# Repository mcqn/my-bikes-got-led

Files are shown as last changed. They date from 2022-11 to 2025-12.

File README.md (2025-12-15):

# My Bike's Got LED
[My Baby's Got LED](https://github.com/mcqn/my-babys-got-led), bike edition. The same [WLED](https://kno.wled.ge/) fun but without being tied to a wall socket.

ibal234-KensingtonFog

My Bike's got LED is a small, battery powered [ESP32 C3](https://www.espressif.com/en/products/socs/esp32-c3) board designed to drive Neopixel/WS2812 LED strips. The original was created for use on bikes, hence the name, but it works just as well for other wearable/portable light projects. It is intended to be usually powered by lipo batteries via a JST terminal, but an additional power bank source can also be attached via the USB-C socket. 
It is in the process of certification with [OSHWA](https://certification.oshwa.org/) 

Boards are shipped with our [getting started zine](https://github.com/mcqn/my-bikes-got-led/blob/main/mybikesgotzine.svg) below is a more detailed discription of how to set up and use My Bike's got LED

### Setting up your bike

The board kit we [sell on Tindie](https://www.tindie.com/products/mcqn_ltd/my-bikes-got-led/) comes with a strip of LEDs already connected to an Amphenol Anytek plug suitable for the on board [four way pluggable terminal block](https://uk.farnell.com/amphenol-anytek/oq0412510000g/terminal-block-r-a-header-4way/dp/3810182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) My Bike's got LED has two main LED data outputs, Data and Clk. The default channel of Data is used, but the secondary output of Clk can also be used if required. (In fact it is possible to use four level shifted outputs to drive for independent light strips if required, see the additonal notes on the [electronics page](https://github.com/mcqn/my-bikes-got-led/tree/main/electronics) if you want to know more about this.) If you are using your own lights connect the three wires, 5V, GND and Data to the screw terminals on the green plug as indicated on the board silkscreen.

Next you will need to attached the lights to your bike, we use velcro ties but if you don't have any cable ties work just as well. They key thing to be aware of here is that the plug end of the light strip is within reach of where you will attach the board. In our kits we provide a saddle bag to store the board and battery, so the plug end of the strips should be close to the seat post. Check first that the strip and socket reach where you would like them, before then securing the lights in place with the ties. Be careful to avoid any moving parts when you secure your lights in place.

Once the lights are secure you can connect them to the board with the green plug, and connect the main battery to the board via the white JST connector. Then turn on the board with the on/off switch. The first thirty lights on your strip will illumate amber. This is the default WLED configuration, information on how to change this is shown in the next step.

### Setting up the board

When a board running WLED is first turned on it will attempt to connect to a known wifi network. If it doesn't have information about a network, or it is out of range, it will instead set up it's own acess point for configuration. The boards we ship have a fresh install of WLED with no knowledge of your network so they will always start in access point mode.  

#### Connecting to wifi

When the board is in access point mode you will be able to connect another device (Mobile/latop) to that network. 

- Open your wifi settings an look for the networked called WLED-AP
- Connect to it and log on with password wled1234

You will arrive at a page with two options. 

- To the controls
- Wifi settings

Use 'To the controls' if you just want to change the settings, this may be all you need to get your board set up.  See 'effects' below for more information on setting the light patterns.

The Wifi settings takes you through the process of connecting the board to a local network, this is useful if you want to change settings without having to connect to the board AP. Once the device is connected to your network you will be able to access the settings page on any other device connected to that network. You will need to add the SSID and password of the network you want to connect to. It's also a good idea to change the mDNS address to something you can recognise, the default is WLED.

More details on wifi set up can be found on the [WLED documentation](https://kno.wled.ge/basics/getting-started/#wifi-setup)

#### Effects

#### Setting up presets

### Adding usermods
Aside from the LED data outputs there are other GPIO pins available to extend the capability of the board, with WLED user mods. 

If you have a [UK000073](https://certification.oshwa.org/uk000073.html) board pins 0, 1, 3, 4 and 10 are available on header J10.

On version [UK000083](https://certification.oshwa.org/uk000083.html) 0, 1, 4 and 10 are in the circular 'Microphone' header, designed to work with INMP441 microphone breakout boards. Pin 3 is available as 'Button' next to the power header.

Both configurations offer the ability to add an 'effects button' to cycle through preprogrammed lighting effects and to implement sound reative effects with an audio input.

#### Effects button

There are times when you might want to cycle through the effects you have set up. 

......

More information about setting up buttons is available in the [WLED documentation](https://kno.wled.ge/features/macros/#buttons)

#### Sound reactive

There are more instructions in the [WLED documentation](https://mm.kno.wled.ge/WLEDSR/Digital-Microphone-Hookup/)

### Updating the software

WLED is an active project and new version are released often. If you need to update to a more current version of the software there are a few options available.

One route is to use the [unofficial online complier tool](https://wled-compile.github.io/) NB. this requires Chrome/Edge browsers for the Web USB upload to work.

- In step 1 select 'esp32c3dev' as the Microcontroller type and in step 3 tick the 'Audio reactive' box, everything else can be left as default.
- Compile the code, step 5 and then install with the instructions described in step 6.
- Follow the prompts to connect to your wifi
- Once connected click the link to see the controls

You will need to configure the default pin settings and number of leds as well as the pins for the audio input device you are using. See [electronics](https://github.com/mcqn/my-bikes-got-led/tree/main/electronics) for more details about the pinouts.

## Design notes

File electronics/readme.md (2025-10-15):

# My Bikes got LED

The hardware for MBiGL is based around the [ESP32 C3 Mini](https://www.espressif.com/sites/default/files/documentation/esp32-c3-mini-1_datasheet_en.pdf) 

## ESPC3-mini Pins Used

| Pin | Function | Note |
| ---- | ---- | ----|
| IO0 | GPIO | - |
| IO1 | GPIO | - |
| IO3 | GPIO | Also available as a level shifted data output by bridging JP42 |
| IO4 | GPIO | Also available as a level shifted data output by bridging JP43 |
| IO5 | LED_data | |
| IO6 | LED_Clock | |
| IO7 | WiFi LED | |
| IO9 | Boot pin | Access via J11 |
| IO10 | Reset pin | See note below |

## Interfaces

### Coding

Code can be uploaded via USB serial or with an external UART board via J31 (six pin header).
More details on the [Espressif website](https://docs.espressif.com/projects/esp-idf/en/latest/esp32c3/get-started/establish-serial-connection.html)

### RGB data outpus

There are four pins available for RGB data output. LED_data (IO5) and LED_clock (IO6) are the primary outputs. IO3 and IO4 are not connected to the level shifter (U4) by default but can be used as additional channels by bridging JP42 and JP43 with solder if required.

**NB IO3/4 are also available as GPIO pins via J10 but cannot be used for both**

### External Crystal

IO0 and IO1 are used by the C3 mini if an external crystal is required. The first revision had footprints for a crystal but this has now been removed as it isn't needed.
These two pins are available via j10 as GPIO

### Additional pins

IO7 is used to drive the Wifi LED indicator D6

IO9 is used to toggle boot modes and can be accessed via J11 See the [C3 technical manual for more details](https://www.espressif.com/sites/default/files/documentation/esp32-c3_technical_reference_manual_en.pdf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)

~~IO10 is connected to the Enable pin via JP4, a breakable bridge. This pin is used for the reset usermod. In addition to the bridge pad there are two unpopulated 0603 resistors here in case an RC circuit is required for timing. R17 has GND and float pads R18 3V3 and float.~~

These have been removed from production boards.

### Headers

J5 and J6 both provde 5v 3v3 and Gnd outputs via 2.54 header

J40 provides 5V, Data, and GND access as an alternative light connection to the socket J2

## Battery management fine tuning

R23-26 are connected to the battery management chip [IP5310](http://www.injoinic.com/wwwroot/uploads/files/20200221/a7a6128e03ee193cf35e48b28e3df9df.pdf) Only R26 is populated but all are available for fine tuning of the charging circuit functions

| Resistor | Name | Default status |  Function |
| ---- | ---- | ---- | ---- |
| R23 | VSET | DNP | Battery voltage selection | 
| R24 | VTHS | DNP | Battery platform selection |
| R25 | RSET | DNP | Set the battery impendence |
| R26 | NTC | 51K | Detect battery pack temperature |

A test point labeled Key1 is available to break out the Key pin on the IP5310 if push button functionality is required

D1-4 are connected to give a four light 'State of Charge' indication

## Alternate board conifguarations

If a thinner board footprint is required there are alternate pads provided for the USB socket and JST battery connector.
Only one each of the following is required

USBC1 or USBC2

J51 or J52

## Changes to board to accomodate INMP441

Issue 38 suggests adaptions to the board to accomodate a footprint and headers for an INMP441 microphone board.

The reset pin has been removed entirely, reset can be achieved via SW3 making IO10 available. 

L/R selection doubles up on a level shifted output so the microphone is not available if this output is enabled (JP43)

| Pin | INMP441 | Note |
| ---- | ---- | ----|
| IO10 | SD | Previously reset pin |
| IO0 | SCK | - |
| IO01 | WS | - |
| IO04 | L/R | Alt available as level shifted output |

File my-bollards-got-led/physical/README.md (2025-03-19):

# Physical Assembly

## Parts

* 1 x My Bike's Got LED board, with USB connector on the short side and the vertical JST-PH battery connector fitted
* 1 x toggle switch
* 1 x inner end-cap
* 1 x PCB to battery adaptor
* 1 x brace
* 1 x 2x2 18650 battery pack, with JST-PH connector
* 2 x LED strip endcaps
* 3 x 29 LED strips
* 3 x LED backing strips
* Some double-sided tape, unless the LED strips are self-adhesive
* Some electricians tape
* 2 x PVC 50mm plumbing end-caps
* 66cm 50MM frosted polycarbonate tube
* 4 x M3 bolts
* 4 x M3 nuts
* ~20cm of ribbon
* Solvent weld
* An elastic band
* 1 x top cap

## Instructions

### Electronics

1. Solder wires to the toggle switch and then to the two terminals on the PCB, with the wires sitting on the underside of the PCB
1. Solder two sets of LED wiring - power/ground/data - to the underside of the PCB, to 5V/GND and Data and Clk
1. Solder the remaining set of LED wiring to 5V/GND/IO3 on the top side of the PCB, with the solder bridge to enable IO3 on the level-shifter
1. Solder the other ends of the LED wires to the LED strips

### Outer Tube

1. Glue the PVC end-caps onto the polycarb tube with solvent weld

### Inner Assembly

1. Stick the LED strips to the backing strips
1. Fasten the toggle switch into the inner-end-cap
1. Bolt the PCB to the inner-end-cap with two M3 nuts and bolts
1. Feed the two sets of LEDs from the underside of the PCB through the side of the PCB-to-battery adaptor with the notch for the brace
1. Feed the remaining set of LEDs through the other side of the PCB-to-battery adaptor
1. Bolt the PCB to the PCB-to-battery adaptor with two M3 nuts and bolts
1. Attach the brace to the PCB-to-battery adaptor and one of the LED strip endcaps
1. Feed the ribbon through the cut-out in the LED strip endcap and then both ends of it through the PCB-top-side hole in the PCB-to-battery adaptor
1. Insert the battery and feed its wiring through the PCB-top-side hole in the PCB-to-battery adaptor
1. Hook the LED strips onto their relative convenient hooks on the LED endcap, routing the wires around the peg
1. Tape the LED wiring to the side of the battery with some electrician tape, to keep it roughly in place.  Spare wire can be fed through to sit alongside the PCB
1. Hook the other end of the LED strips onto the other LED strip endcap

### Final Assembly

1. Feed some string or wool through the tube, and then through the cut-out in the not-PCB-end LED strip endcap
1. Attach the elastic band through the not-PCB-end LED strip endcap
1. Slowly pull the inner assembly through the tube until the PCB end cap seats onto the PVC endcap
1. Attach the elastic band from the top LED tensioner

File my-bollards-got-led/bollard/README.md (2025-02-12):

| Supported Targets | ESP32 | ESP32-C2 | ESP32-C3 | ESP32-C5 | ESP32-C6 | ESP32-C61 | ESP32-H2 | ESP32-S3 |
| --- | ----- | --- | --- | --- | --- | --- | --- | --- |

ESP-IDF Combined Bluetooth advertising and scanning
===================================================

Copy of this sample as base for Bollard code
todo edit this document to reflect changes to functionality

Have a fixed bollard number 1-4

Separate tasks to manage Bluetooth comms and display

Bluetooth
Maintain list of Parcel devices within given range (RSSI) over the last five seconds and if they are at the correct bollard or not

Listen for Set/Check/Reset broadcasts from controller. Use a hop counter when rebroadcasting this signal to other bollards to extend the range

On Set call display to enter waiting mode
On Check call correct/incorrect display based on state of Parcel devices seen list
On Reset enter waiting mode

Display
Receive calls to set lights based on game state. Ideally animated sequences

This is a Bluetooth advertising and scanning demo with virtual HCI interface. Send Reset, ADV_PARAM, ADV_DATA and HCI_ADV_ENABLE command for BLE advertising. And SET_EVENT_MASK, SCAN_PARAMS and SCAN_START commands for BLE scanning. Scanned advertising reports from other devices are also displayed.

In this example no host is used. But some of the functionalities of a host are implemented.

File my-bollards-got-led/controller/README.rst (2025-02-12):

.. zephyr:code-sample:: ble_peripheral
   :name: Peripheral
   :relevant-api: bt_gatt bluetooth

   Implement basic Bluetooth LE Peripheral role functionality (advertising and exposing GATT services).

Copy of this sample as base for Controller code
todo edit this document to reflect changes to functionality

Manages the game running with button presses

    A Set the game: Broadcast to all bollards to enter waiting mode
    B Check: Broadcast to all the bollards to check status and display correct/incorrect indicator
    A+B Reset Broadcast to all the Parcels to generate a random destination number 1-4 and broadcast to bollards to enter waiting mode

Overview
********

Application demonstrating the Bluetooth LE Peripheral role. It has several well-known and
vendor-specific GATT services that it exposes.

Requirements
************

* BlueZ running on the host, or
* A board with Bluetooth LE support

Building and Running
********************

This sample can be found under :zephyr_file:`samples/bluetooth/peripheral` in the
Zephyr tree.

See :zephyr:code-sample-category:`bluetooth` samples for details.

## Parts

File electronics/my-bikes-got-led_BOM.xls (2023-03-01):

References | Qty | Description | Farnell | Farnell Price/Stock | LCSC | LCSC Price/Stock | Manuf# | description
5V_T1, Clk_T1, Data_T1 | 3 | DNP
BT1 | 1 |  | 9492615 | https://uk.farnell.com/jst-japan-solderless-terminals/s2b-ph-sm4-tb-lf-sn/connector-header-smt-r-a-2mm-2way/dp/9492615
C1, C4 | 2 |  | C342632 | https://www.lcsc.com/product-detail/Multilayer-Ceramic-Capacitors-MLCC-SMD-SMT_TDK-C4532X7R1C226MT000N_C342632.html | C342632 | https://www.lcsc.com/product-detail/Multilayer-Ceramic-Capacitors-MLCC-SMD-SMT_TDK-C4532X7R1C226MT000N_C342632.html
C3 | 1 |  | C28504 | https://www.lcsc.com/product-detail/Multilayer-Ceramic-Capacitors-MLCC-SMD-SMT_FH_1812X226K250NT_22uF-226-10-25V_C28504.html | C28504 | https://www.lcsc.com/product-detail/Multilayer-Ceramic-Capacitors-MLCC-SMD-SMT_FH_1812X226K250NT_22uF-226-10-25V_C28504.html
C5 | 1 |  | C342632 | https://www.lcsc.com/product-detail/Multilayer-Ceramic-Capacitors-MLCC-SMD-SMT_TDK-C4532X7R1C226MT000N_C342632.html | C342632 | https://www.lcsc.com/product-detail/Multilayer-Ceramic-Capacitors-MLCC-SMD-SMT_TDK-C4532X7R1C226MT000N_C342632.html
C6, C8 | 2 |  | C28504 | https://www.lcsc.com/product-detail/Multilayer-Ceramic-Capacitors-MLCC-SMD-SMT_FH_1812X226K250NT_22uF-226-10-25V_C28504.html | C28504 | https://www.lcsc.com/product-detail/Multilayer-Ceramic-Capacitors-MLCC-SMD-SMT_FH_1812X226K250NT_22uF-226-10-25V_C28504.html
C7 | 1 |  | 1759038RL | https://uk.farnell.com/multicomp/mc0603f104z250ct/cap-0-1-f-25v-y5v-0603/dp/1759038RL
C9 | 1 |  | 1759031 | https://uk.farnell.com/multicomp/mc0603b473k250ct/cap-0-047-f-25v-10-x7r-0603/dp/1759031
C10 | 1 |  | 3013512 | https://uk.farnell.com/samsung-electro-mechanics/cl31a106kbhnnne/cap-10uf-50v-mlcc-1206/dp/3013512
C11, C14 | 2 |  | 2211179 | https://uk.farnell.com/tdk/c1608x5r1h105k080ab/cap-1-f-50v-10-x5r-0603/dp/2211179
C12 | 1 |  | 2346906 | https://uk.farnell.com/tdk/c1608x7r1h224k080ab/cap-0-22-f-50v-10-x7r-0603/dp/2346906
C13, C16 | 2 |  | 1759122 | https://uk.farnell.com/multicomp/mc0603b104k500ct/cap-0-1-f-50v-10-x7r-0603/dp/1759122
C15 | 1 |  | 3013512 | https://uk.farnell.com/samsung-electro-mechanics/cl31a106kbhnnne/cap-10uf-50v-mlcc-1206/dp/3013512
D1, D2 | 2 |  | 2322102 | https://uk.farnell.com/wurth-elektronik/155124vs73200/led-1204-b-green-50mcd-573nm/dp/2322102
D3 | 1 |  | 3796308 | https://uk.farnell.com/multicomp-pro/mp008279/led-green-70mcd-576nm-0805/dp/3796308
D4 | 1 |  | 3796325 | https://uk.farnell.com/multicomp-pro/mp008293/led-red-220mcd-626nm-0805/dp/3796325
D5, D6, D7 | 3 |  | 3014176 | https://uk.farnell.com/vishay/v3fl45hm3-h/schottky-rect-single-3a-45v-do/dp/3014176
D8 | 1 |  | 2844819 | https://uk.farnell.com/on-semiconductor/mm3z4v3st1g/zener-diode-4-3v-0-2w-sod-323/dp/2844819
F1, F2 | 2 |  | 1861167RL | https://uk.farnell.com/multicomp/mc36225/fuse-ptc-reset-smd-24v-1-1a/dp/1861167RL
J1 | 1 |  | 3367461 | https://uk.farnell.com/amphenol-fci/12401610e4-2a/usb-conn-3-1-type-c-rcpt-smd/dp/3367461
J2 | 1 |  | 3810182 | https://uk.farnell.com/amphenol-anytek/oq0412510000g/terminal-block-r-a-header-4way/dp/3810182
J3 | 1 |  | 1593412 | https://uk.farnell.com/multicomp/2211s-03g/header-1-row-vert-3way/dp/1593412
J4 | 1 | DNP
J5, J6 | 2 | DNP |  |  |  |  |  | dnp
J7 | 1 | DNP
J8 | 1 | DNP
JP1 | 1 | DNP
JP2 | 1 | DNP
JP3 | 1 | DNP
JP4 | 1 | DNP
JP5 | 1 | DNP
JP6 | 1 | DNP
L1 | 1 |  | C27442 | https://www.lcsc.com/product-detail/Power-Inductors_ReliaPro_SMRH74-220MT_22uH_C27442.html | C27442 | https://www.lcsc.com/product-detail/Power-Inductors_ReliaPro_SMRH74-220MT_22uH_C27442.html
L2 | 1 |  | 2374058 | https://uk.farnell.com/bourns/srf1260a-1r5y/inductor-dual-1-5uh-18-3a-pwr/dp/2374058
L3 | 1 |  | 3380989 | https://uk.farnell.com/wurth-elektronik/7447706101/inductor-aec-q200-100uh-shld-1/dp/3380989
P1, P2 | 2 | DNP
P3, P4 | 2 | DNP
Q1, Q4 | 2 |  | 2769528 | https://uk.farnell.com/rohm/rrr040p03fratl/mosfet-aec-q101-p-ch-30v-tsmt/dp/2769528
Q2 | 1 |  | C32254 | https://www.lcsc.com/product-detail/MOSFET_FORTUNE_FS8205_FS8205_C32254.html | C32254 | https://www.lcsc.com/product-detail/MOSFET_FORTUNE_FS8205_FS8205_C32254.html
Q3 | 1 |  | C916403 | https://www.lcsc.com/product-detail/MOSFETs_JSMSEMI-JSM2302_C916403.html | C916403 | https://www.lcsc.com/product-detail/MOSFETs_JSMSEMI-JSM2302_C916403.html
R1 | 1 |  | 3994449 | https://uk.farnell.com/walsin/mr06x105-jtlv/res-1m-5-0-125w-0603-thick-film/dp/3994449
R2, R3 | 2 |  | 2447404 | https://uk.farnell.com/multicomp/mcwr06x5101ftl/res-5k1-1-0-1w-0603-thick-film/dp/2447404
R4, R26 | 2 |  | 2331740 | https://uk.farnell.com/te-connectivity/crgh0603j10k/res-10k-5-0-2w-0603-thick-film/dp/2331740
R5, R6 | 2 |  | 2502462 | https://uk.farnell.com/walsin/wr06x4700ftl/res-470r-1-75v-0603-thick-film/dp/2502462
R7 | 1 |  | 2073501 | https://uk.farnell.com/multicomp/mcmr06x4302ftl/res-43k-1-0-1w-0603-ceramic/dp/2073501
R8 | 1 |  | 3950855 | https://uk.farnell.com/yageo/rc0603fr-0773k2l/res-73k2-1-0-1w-thick-film-0603/dp/3950855
R9 | 1 |  | 2331740 | https://uk.farnell.com/te-connectivity/crgh0603j10k/res-10k-5-0-2w-0603-thick-film/dp/2331740
R10 | 1 |  | 2447449 | https://uk.farnell.com/multicomp/mcwr06x9102ftl/res-91k-1-0-1w-thick-film/dp/2447449
R11 | 1 |  | 2447293 | https://uk.farnell.com/multicomp/mcwr06x2002ftl/res-20k-1-0-1w-thick-film/dp/2447293
R12, R15, R16 | 3 |  | 2502470 | https://uk.farnell.com/walsin/wr06x5600ftl/res-560r-1-75v-0603-thick-film/dp/2502470
R13, R17 | 2 |  | 2331740 | https://uk.farnell.com/te-connectivity/crgh0603j10k/res-10k-5-0-2w-0603-thick-film/dp/2331740
R14 | 1 |  | 2331740 | https://uk.farnell.com/te-connectivity/crgh0603j10k/res-10k-5-0-2w-0603-thick-film/dp/2331740
R18 | 1 |  | 2502470 | https://uk.farnell.com/walsin/wr06x5600ftl/res-560r-1-75v-0603-thick-film/dp/2502470
R19 | 1 |  | 2447240 | https://uk.farnell.com/multicomp/mcwr06x1200ftl/res-120r-1-0-1w-thick-film/dp/2447240
R20 | 1 |  | 2447338 | https://uk.farnell.com/multicomp/mcwr06x3303ftl/res-330k-1-0-1w-thick-film/dp/2447338
R21 | 1 |  | 2447339 | https://uk.farnell.com/multicomp/mcwr06x3300ftl/res-330r-1-0-1w-0603-thick-film/dp/2447339
R22 | 1 |  | 2447319 | https://uk.farnell.com/multicomp/mcwr06x2001ftl/res-2k-1-0-1w-0603-thick-film/dp/2447319
R23 | 1 |  | 2483502 | https://uk.farnell.com/te-connectivity/tlm2aer068jte/current-sense-res-0r068-5-250/dp/2483502
R24 | 1 |  | 2694684 | https://uk.farnell.com/multicomp/mcwr06x101-jtl/res-100r-5-0-1w-0603-thick-film/dp/2694684
R25, R29 | 2 |  | 2073355 | https://uk.farnell.com/multicomp/mcmr06x1023ftl/res-102k-1-0-1w-0603-ceramic/dp/2073355
R27 | 1 |  | 2331740 | https://uk.farnell.com/te-connectivity/crgh0603j10k/res-10k-5-0-2w-0603-thick-film/dp/2331740
R28 | 1 |  | 2694684 | https://uk.farnell.com/multicomp/mcwr06x101-jtl/res-100r-5-0-1w-0603-thick-film/dp/2694684
SW1 | 1 |  | 2435308 | http://uk.farnell.com/c-k-components/ksek43g-lfs/tactile-switch-spst-0-05a-32vdc/dp/2435308
SW2 | 1 |  | 1201431 | https://uk.farnell.com/c-k-components/os102011ma1qn1/switch-spdt-0-1a-12v-pcb-r-a/dp/1201431
T1, T2 | 2 | DNP
U1 | 1 |  | C82652 | https://www.lcsc.com/product-detail/DC-DC-Converters_Advanced-Analog-Technology-FP6276BXR-G1_C82652.html | C82652 | https://www.lcsc.com/product-detail/DC-DC-Converters_Advanced-Analog-Technology-FP6276BXR-G1_C82652.html
U2 | 1 |  | 3006129 | https://uk.farnell.com/texas-instruments/sn74ahct125d/ic-buffer-gate-quad-3state-smd/dp/3006129
U3 | 1 |  | 2729771 | https://uk.farnell.com/richtek/rt8097bhgb/dc-dc-conv-sync-buck-1mhz-sot/dp/2729771
U4 | 1 | ESP-WROOM-02 free issue |  |  |  |  | ESP-WROOM-02
U5 | 1 |  | C154992 | https://www.lcsc.com/product-detail/Battery-Management-ICs_ShangHai-Consonance-Elec-CN3791_C154992.html | C154992 | https://www.lcsc.com/product-detail/Battery-Management-ICs_ShangHai-Consonance-Elec-CN3791_C154992.html
U6 | 1 |  | C82736 | https://www.lcsc.com/product-detail/Battery-Protection-ICs_FORTUNE_FS312F-G_FS312F-G_C82736.html | C82736 | https://www.lcsc.com/product-detail/Battery-Protection-ICs_FORTUNE_FS312F-G_FS312F-G_C82736.html

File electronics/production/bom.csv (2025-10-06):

Designator | Footprint | Quantity | Value | LCSC Part #
5V_T1, CLK_T1, DATA_T1 | TestPoint_Pad_D2.0mm | 3 | Conn_01x01
C1 | 0603 | 1 | 10uF | C76614
C10, C41 | 0603 | 2 | 0.1uF/50V(10%) | C237171
C11 | 0603 | 1 | 10uF/25V(20%) | C76614
C12 | 0603 | 1 | 1uF/16V(10%) | C85862
C2 | 0603 | 1 | 10uF | C76614
C20, C21 | 0402 | 2 | 22uF | C2179118
C22, C23, C24, C25 | 0402 | 4 | 22uF | C2179118
C31 | 0805 | 1 | 22uF X5R | C128856
C32 | 0805 | 1 | 22uF X5R | C128856
D1, D2, D3, D4 | 0805 | 4 | LED | C965814
D6 | 0805 | 1 | LED | C965815
EN1, EN2 | TestPoint_Pad_D2.5mm | 2 | TestPoint
F1 | 1812 | 1 | Polyfuse | C369172
J12, J13 | PinHeader_1x03_P2.54mm_Vertical | 2 | Conn_01x03
J14 | PinHeader_1x01_P2.54mm_Vertical | 1 | Conn_01x01_Pin
J51 | JST_PH_S2B-PH-SM4-TB_1x02-1MP_P2.00mm_Horizontal | 1 | Battery | C295747
JP42 | SolderJumper-2_P1.3mm_Open_RoundedPad1.0x1.5mm | 1 | P3 EN
JP43 | SolderJumper-2_P1.3mm_Open_RoundedPad1.0x1.5mm | 1 | p16 EN
JP5 | SolderJumper-2_P1.3mm_Open_RoundedPad1.0x1.5mm | 1 | Jumper_on
KEY1 | TestPoint_Pad_D2.0mm | 1 | TestPoint
L2 | IND-SMD_L11.6-W10.1 | 1 | MHCC10040-1R0M-R7 | C280565
L3 | L_Vishay_IHLP-2525 | 1 | 1.5uH | C845020
Q1 | SOT-23 | 1 | JSM2302 | C916403
R1 | 0402 | 1 | 1M | C26083
R11, R22 | 0603 | 2 | 10k | C95204
R12 | 0402 | 1 | R560 | C163460
R13, R14 | 0402 | 2 | 10k | C2073569
R15, R16 | 0402 | 2 | 22 | C25092
R2, R3 | 0402 | 2 | 5.1K | C103079
R20 | 0402 | 1 | 0 | C17168
R21 | 0603 | 1 | 100K | C667752
R26 | 0603 | 1 | 51K | C269448
R27 | 0603 | 1 | R120 | C22787
R31 | 0603 | 1 | 91K | C23265
R32 | 0603 | 1 | 20K | C136589
R4 | 0603 | 1 | 2R | C445777
R41, R42, R5, R6 | 0603 | 4 | 470R | C144600
U1 | WIFIM-SMD_ESP32-C3-MINI-1 | 1 | ESP32-C3-MINI-1-N4 | C2838502
U2 | QFN-32_L5.0-W5.0-P0.50-BL-EP3.4 | 1 | IP5310 | C191176
U3 | SOT-23-5 | 1 | RT8097B | C3031686
U4 | HTSSOP-14-1EP_4.4x5mm_P0.65mm_EP3.4x5mm_Mask3x3.1mm | 1 | SN74AHCT125 | C36365
USBC1 | USB-C-SMD_TYPE-C-USB-18 | 1 | 105450-0101 | C134092

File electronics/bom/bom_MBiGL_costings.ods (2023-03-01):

EUROPEAN CIRCUITS LIMITED - EXAMPLE BILL OF MATERIALS (BOM)
SALES@EUROPEAN-CIRCUITS.CO.UK
Place your mouse over the red comment markers in the top right corner of the cells in the row below to see more info on the data in that column
Company Name: |  |  | MCQN
Board Reference: |  |  | My Bike’s got LED
Revision Number: |  |  | r20221221
1 | 2 | 3 | 4 | 5 | 6 | 7 | 8 | 9 | 10 | 11 | Component costs
Sequential Item Nos | Consolidated quantity of each Part No | Component ID's separated by Commas | Confirmation Yes or No Parts are fitted this Build (Note 1) | Full Description of Part e.g. for capacitor include value, tolerance and type or Dielectric | Value or Type No | Case Style | Supplier or Manufacturer (Note 2) | Supplier Stock No or Manufacturer's Part No (Note 2) | Side of Board Mounted | PTH or SMT | For 6 |  | For 100
Item | Qty | Reference | Fit | Part Description | Value | Package | Supplier | Supplier Ref | Side | Mount Type | ea |  | ea
1 | 3 | 5V_T1, Clk_T1, Data_T1 | DNP |  |  |  |  |  | F |  | 0 |  | 0
2 | 1 | BT1 | Y |  |  |  | https://uk.farnell.com/jst-japan-solderless-terminals/s2b-ph-sm4-tb-lf-sn/connector-header-smt-r-a-2mm-2way/dp/9492615 | 9492615 | F |  | 0.4752 | 2.8512 | 0.3924 | 39.24
3 | 2 | C1, C4 | Y |  |  |  | https://www.lcsc.com/product-detail/Multilayer-Ceramic-Capacitors-MLCC-SMD-SMT_TDK-C4532X7R1C226MT000N_C342632.html | C342632 | F |  | 0.51 | 6.12 | 0.5048 | 100.96
4 | 1 | C3 | Y |  |  |  | https://www.lcsc.com/product-detail/Multilayer-Ceramic-Capacitors-MLCC-SMD-SMT_FH_1812X226K250NT_22uF-226-10-25V_C28504.html | C28504 | F |  | 0.6486 | 3.8916 | 0.4354 | 43.54
5 | 1 | C5 | Y |  |  |  | https://www.lcsc.com/product-detail/Multilayer-Ceramic-Capacitors-MLCC-SMD-SMT_TDK-C4532X7R1C226MT000N_C342632.html | C342632 | F |  | 0.5137 | 3.0822 | 0.5048 | 50.48
6 | 2 | C6, C8 | Y |  |  |  | https://www.lcsc.com/product-detail/Multilayer-Ceramic-Capacitors-MLCC-SMD-SMT_FH_1812X226K250NT_22uF-226-10-25V_C28504.html | C28504 | F |  | 0.6486 | 7.7832 | 0.4354 | 87.08
7 | 1 | C7 | Y |  |  |  | https://uk.farnell.com/multicomp/mc0603f104z250ct/cap-0-1-f-25v-y5v-0603/dp/1759038RL | 1759038RL | F |  | 0.0256 | 0.1536 | 0.0256 | 2.56
8 | 1 | C9 | Y |  |  |  | https://uk.farnell.com/multicomp/mc0603b473k250ct/cap-0-047-f-25v-10-x7r-0603/dp/1759031 | 1759031 | F |  | 0.0443 | 0.2658 | 0.0332 | 3.32
9 | 1 | C10 | Y |  |  |  | https://uk.farnell.com/samsung-electro-mechanics/cl31a106kbhnnne/cap-10uf-50v-mlcc-1206/dp/3013512 | 3013512 | F |  | 0.3072 | 1.8432 | 0.186 | 18.6
10 | 2 | C11, C14 | Y |  |  |  | https://uk.farnell.com/tdk/c1608x5r1h105k080ab/cap-1-f-50v-10-x5r-0603/dp/2211179 | 2211179 | F |  | 0.0865 | 1.038 | 0.0727 | 14.54
11 | 1 | C12 | Y |  |  |  | https://uk.farnell.com/tdk/c1608x7r1h224k080ab/cap-0-22-f-50v-10-x7r-0603/dp/2346906 | 2346906 | F |  | 0.0826 | 0.4956 | 0.0688 | 6.88
12 | 2 | C13, C16 | Y |  |  |  | https://uk.farnell.com/multicomp/mc0603b104k500ct/cap-0-1-f-50v-10-x7r-0603/dp/1759122 | 1759122 | F |  | 0.0306 | 0.3672 | 0.023 | 4.6
13 | 1 | C15 | Y |  |  |  | https://uk.farnell.com/samsung-electro-mechanics/cl31a106kbhnnne/cap-10uf-50v-mlcc-1206/dp/3013512 | 3013512 | F |  | 0.3072 | 1.8432 | 0.186 | 18.6
14 | 2 | D1, D2 | Y |  |  |  | https://uk.farnell.com/wurth-elektronik/155124vs73200/led-1204-b-green-50mcd-573nm/dp/2322102 | 2322102 | F |  | 0.2232 | 2.6784 | 0.1728 | 34.56
15 | 1 | D3 | Y |  |  |  | https://uk.farnell.com/multicomp-pro/mp008279/led-green-70mcd-576nm-0805/dp/3796308 | 3796308 | F |  | 0.1284 | 0.7704 | 0.0853 | 8.53
16 | 1 | D4 | Y |  |  |  | https://uk.farnell.com/multicomp-pro/mp008293/led-red-220mcd-626nm-0805/dp/3796325 | 3796325 | F |  | 0.1184 | 0.7104 | 0.079 | 7.9
17 | 3 | D5, D6, D7 | Y |  |  |  | https://uk.farnell.com/vishay/v3fl45hm3-h/schottky-rect-single-3a-45v-do/dp/3014176 | 3014176 | F |  | 0.4224 | 7.6032 | 0.2004 | 60.12
18 | 1 | D8 | Y |  |  |  | https://uk.farnell.com/on-semiconductor/mm3z4v3st1g/zener-diode-4-3v-0-2w-sod-323/dp/2844819 | 2844819 | F |  | 0.1692 | 1.0152 | 0.084 | 8.4
19 | 2 | F1, F2 | Y |  |  |  | https://uk.farnell.com/multicomp/mc36225/fuse-ptc-reset-smd-24v-1-1a/dp/1861167RL | 1861167RL | F |  | 0.1572 | 1.8864 | 0.1572 | 31.44 | Min order 100
20 | 1 | J1 | Y |  |  |  | https://uk.farnell.com/amphenol-fci/12401610e4-2a/usb-conn-3-1-type-c-rcpt-smd/dp/3367461 | 3367461 | F |  | 1.896 | 11.376 | 1.896 | 189.6
21 | 1 | J2 | Y |  |  |  | https://uk.farnell.com/amphenol-anytek/oq0412510000g/terminal-block-r-a-header-4way/dp/3810182 | 3810182 | F |  | 0.414 | 2.484 | 0.3072 | 30.72 | Min order 10
22 | 1 | J3 | Y |  |  |  | https://uk.farnell.com/multicomp/2211s-03g/header-1-row-vert-3way/dp/1593412 | 1593412 | F |  | 0.0205 | 0.123 | 0.0205 | 2.05 | Min order 50 | Not needed?
23 | 1 | J4 | DNP |  |  |  |  |  | F |  | 0 |  | 0
24 | 2 | J5, J6 | DNP |  |  |  |  |  | F |  | 0 |  | 0
25 | 1 | J7 | DNP |  |  |  |  |  | F |  | 0 |  | 0
26 | 1 | J8 | DNP |  |  |  |  |  | F |  | 0 |  | 0
27 | 1 | JP1 | DNP |  |  |  |  |  | F |  | 0 |  | 0
28 | 1 | JP2 | DNP |  |  |  |  |  | F |  | 0 |  | 0
29 | 1 | JP3 | DNP |  |  |  |  |  | F |  | 0 |  | 0
30 | 1 | JP4 | DNP |  |  |  |  |  | F |  | 0 |  | 0
31 | 1 | JP5 | DNP |  |  |  |  |  | F |  | 0 |  | 0
32 | 1 | JP6 | DNP |  |  |  |  |  | F |  | 0 |  | 0
33 | 1 | L1 | Y |  |  |  | https://www.lcsc.com/product-detail/Power-Inductors_ReliaPro_SMRH74-220MT_22uH_C27442.html | C27442 | F |  | 0.1574 | 0.9444 | 0.1277 | 12.77
34 | 1 | L2 | Y |  |  |  | https://uk.farnell.com/bourns/srf1260a-1r5y/inductor-dual-1-5uh-18-3a-pwr/dp/2374058 | 2374058 | F |  | 1.536 | 9.216 | 1.0368 | 103.68
35 | 1 | L3 | Y |  |  |  | https://uk.farnell.com/wurth-elektronik/7447706101/inductor-aec-q200-100uh-shld-1/dp/3380989 | 3380989 | F |  | 1.308 | 7.848 | 1.0308 | 103.08
36 | 2 | P1, P2 | DNP |  |  |  |  |  | F |  | 0 |  | 0
37 | 2 | P3, P4 | DNP |  |  |  |  |  | F |  | 0 |  | 0
38 | 2 | Q1, Q4 | Y |  |  |  | https://uk.farnell.com/rohm/rrr040p03fratl/mosfet-aec-q101-p-ch-30v-tsmt/dp/2769528 | 2769528 | F |  | 0.8448 | 10.1376 | 0.5904 | 118.08
39 | 1 | Q2 | Y |  |  |  | https://www.lcsc.com/product-detail/MOSFET_FORTUNE_FS8205_FS8205_C32254.html | C32254 | F |  | 0.1489 | 0.8934 | 0.1208 | 12.08
40 | 1 | Q3 | Y |  |  |  | https://www.lcsc.com/product-detail/MOSFETs_JSMSEMI-JSM2302_C916403.html | C916403 | F |  | 0.0226 | 0.1356 | 0.0226 | 2.26 | Min order 20
41 | 1 | R1 | Y |  |  |  | https://uk.farnell.com/walsin/mr06x105-jtlv/res-1m-5-0-125w-0603-thick-film/dp/3994449 | 3994449 | F |  | 0.0028 | 0.0168 | 0.0026 | 0.26 | Min order 10
42 | 2 | R2, R3 | Y |  |  |  | https://uk.farnell.com/multicomp/mcwr06x5101ftl/res-5k1-1-0-1w-0603-thick-film/dp/2447404 | 2447404 | F |  | 0.0049 | 0.0588 | 0.0046 | 0.92 | Min order 10
43 | 2 | R4, R26 | Y |  |  |  | https://uk.farnell.com/te-connectivity/crgh0603j10k/res-10k-5-0-2w-0603-thick-film/dp/2331740 | 2331740 | F |  | 0.0269 | 0.3228 | 0.0269 | 5.38 | Min order 10
44 | 2 | R5, R6 | Y |  |  |  | https://uk.farnell.com/walsin/wr06x4700ftl/res-470r-1-75v-0603-thick-film/dp/2502462 | 2502462 | F |  | 0.0146 | 0.1752 | 0.0053 | 1.06 | Min order 10
45 | 1 | R7 | Y |  |  |  | https://uk.farnell.com/multicomp/mcmr06x4302ftl/res-43k-1-0-1w-0603-ceramic/dp/2073501 | 2073501 | F |  | 0.0092 | 0.0552 | 0.008 | 0.8 | Min order 10
46 | 1 | R8 | Y |  |  |  | https://uk.farnell.com/yageo/rc0603fr-0773k2l/res-73k2-1-0-1w-thick-film-0603/dp/3950855 | 3950855 | F |  | 0.0144 | 0.0864 | 0.0048 | 0.48 | Min order 10
47 | 1 | R9 | Y |  |  |  | https://uk.farnell.com/te-connectivity/crgh0603j10k/res-10k-5-0-2w-0603-thick-film/dp/2331740 | 2331740 | F |  | 0.0226 | 0.1356 | 0.0226 | 2.26
48 | 1 | R10 | Y |  |  |  | https://uk.farnell.com/multicomp/mcwr06x9102ftl/res-91k-1-0-1w-thick-film/dp/2447449 | 2447449 | F |  | 0.0226 | 0.1356 | 0.0226 | 2.26
49 | 1 | R11 | Y |  |  |  | https://uk.farnell.com/multicomp/mcwr06x2002ftl/res-20k-1-0-1w-thick-film/dp/2447293 | 2447293 | F |  | 0.0226 | 0.1356 | 0.0226 | 2.26
50 | 3 | R12, R15, R16 | Y |  |  |  | https://uk.farnell.com/walsin/wr06x5600ftl/res-560r-1-75v-0603-thick-film/dp/2502470 | 2502470 | F |  | 0.0226 | 0.4068 | 0.0226 | 6.78
51 | 2 | R13, R17 | Y |  |  |  | https://uk.farnell.com/te-connectivity/crgh0603j10k/res-10k-5-0-2w-0603-thick-film/dp/2331740 | 2331740 | F |  | 0.0226 | 0.2712 | 0.0226 | 4.52
52 | 1 | R14 | Y |  |  |  | https://uk.farnell.com/te-connectivity/crgh0603j10k/res-10k-5-0-2w-0603-thick-film/dp/2331740 | 2331740 | F |  | 0.0226 | 0.1356 | 0.0226 | 2.26
53 | 1 | R18 | Y |  |  |  | https://uk.farnell.com/walsin/wr06x5600ftl/res-560r-1-75v-0603-thick-film/dp/2502470 | 2502470 | F |  | 0.0226 | 0.1356 | 0.0226 | 2.26
54 | 1 | R19 | Y |  |  |  | https://uk.farnell.com/multicomp/mcwr06x1200ftl/res-120r-1-0-1w-thick-film/dp/2447240 | 2447240 | F |  | 0.0226 | 0.1356 | 0.0226 | 2.26
55 | 1 | R20 | Y |  |  |  | https://uk.farnell.com/multicomp/mcwr06x3303ftl/res-330k-1-0-1w-thick-film/dp/2447338 | 2447338 | F |  | 0.0226 | 0.1356 | 0.0226 | 2.26
56 | 1 | R21 | Y |  |  |  | https://uk.farnell.com/multicomp/mcwr06x3300ftl/res-330r-1-0-1w-0603-thick-film/dp/2447339 | 2447339 | F |  | 0.0226 | 0.1356 | 0.0226 | 2.26
57 | 1 | R22 | Y |  |  |  | https://uk.farnell.com/multicomp/mcwr06x2001ftl/res-2k-1-0-1w-0603-thick-film/dp/2447319 | 2447319 | F |  | 0.0226 | 0.1356 | 0.0226 | 2.26
58 | 1 | R23 | Y |  |  |  | https://uk.farnell.com/te-connectivity/tlm2aer068jte/current-sense-res-0r068-5-250/dp/2483502 | 2483502 | F |  | 0.0226 | 0.1356 | 0.0226 | 2.26
59 | 1 | R24 | Y |  |  |  | https://uk.farnell.com/multicomp/mcwr06x101-jtl/res-100r-5-0-1w-0603-thick-film/dp/2694684 | 2694684 | F |  | 0.0226 | 0.1356 | 0.0226 | 2.26
60 | 2 | R25, R29 | Y |  |  |  | https://uk.farnell.com/multicomp/mcmr06x1023ftl/res-102k-1-0-1w-0603-ceramic/dp/2073355 | 2073355 | F |  | 0.0226 | 0.2712 | 0.0226 | 4.52
61 | 1 | R27 | Y |  |  |  | https://uk.farnell.com/te-connectivity/crgh0603j10k/res-10k-5-0-2w-0603-thick-film/dp/2331740 | 2331740 | F |  | 0.0269 | 0.1614 | 0.0269 | 2.69 | Min order 10
62 | 1 | R28 | Y |  |  |  | https://uk.farnell.com/multicomp/mcwr06x101-jtl/res-100r-5-0-1w-0603-thick-film/dp/2694684 | 2694684 | F |  | 0.0048 | 0.0288 | 0.0044 | 0.44 | Min order 10
63 | 1 | SW1 | Y |  |  |  | http://uk.farnell.com/c-k-components/ksek43g-lfs/tactile-switch-spst-0-05a-32vdc/dp/2435308 | 2435308 | F |  | 0.4296 | 2.5776 | 0.3516 | 35.16 | Min order 10
64 | 1 | SW2 | Y |  |  |  | https://uk.farnell.com/c-k-components/os102011ma1qn1/switch-spdt-0-1a-12v-pcb-r-a/dp/1201431 | 1201431 | F |  | 0.5256 | 3.1536 | 0.438 | 43.8 | Min order 10
65 | 2 | T1, T2 | DNP |  |  |  |  |  | F |  | 0 |  | 0
66 | 1 | U1 | Y |  |  |  | https://www.lcsc.com/product-detail/DC-DC-Converters_Advanced-Analog-Technology-FP6276BXR-G1_C82652.html | C82652 | F
67 | 1 | U2 | Y |  |  |  | https://uk.farnell.com/texas-instruments/sn74ahct125d/ic-buffer-gate-quad-3state-smd/dp/3006129 | 3006129 | F |  | 2.196 | 13.176 | 1.32 | 132
68 | 1 | U3 | Y |  |  |  | https://uk.farnell.com/richtek/rt8097bhgb/dc-dc-conv-sync-buck-1mhz-sot/dp/2729771 | 2729771 | F |  | 0.289 | 1.734 | 0.289 | 28.9 | https://www.lcsc.com/product-detail/DC-DC-Converters_Richtek-Tech-RT8097BHGE_C3200266.html
69 | 1 | U4 | ESP-WROOM-02 free issue |  |  |  |  |  | F |  | 0 |  | 0
70 | 1 | U5 | Y |  |  |  | https://www.lcsc.com/product-detail/Battery-Management-ICs_ShangHai-Consonance-Elec-CN3791_C154992.html | C154992 | F |  | 0.497 | 2.982 | 0.3494 | 34.94
71 | 1 | U6 | Y |  |  |  | https://www.lcsc.com/product-detail/Battery-Protection-ICs_FORTUNE_FS312F-G_FS312F-G_C82736.html | C82736 | F |  | 0.119 | 0.714 | 0.099 | 9.9
 |  |  |  |  |  |  |  |  |  |  | For all | 115.2402 |  | 1453.08
 |  |  |  |  |  |  |  |  |  |  | Each | 19.2067 |  | 14.5308

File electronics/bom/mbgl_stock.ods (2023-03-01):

null | Sourced | Placed | References | Value | Footprint | Quantity | Stock
1 |  |  | C1, C6, C7 | 470uF | C_Elec_10x10.2 | 3 | 11
2 |  |  | C3, C5 | 0.1uF | C_0603_1608Metric_Pad1.05x0.95mm_HandSolder | 2
3 |  |  | C2 | C47nF | C_0603_1608Metric_Pad1.05x0.95mm_HandSolder | 1
4 | ✓ |  | C4 | 10uF | C_1206_3216Metric_Pad1.42x1.75mm_HandSolder | 1
5 |  |  | R6, R7, R8, R9 | R560 | R_0603_1608Metric_Pad1.05x0.95mm_HandSolder | 4
6 | ✓ |  | R1, R2, R10 | R10k | R_0603_1608Metric_Pad1.05x0.95mm_HandSolder | 3
7 |  |  | R3, R4, R5 | 470R | R_0603_1608Metric_Pad1.05x0.95mm_HandSolder | 3
8 |  |  | D4, D5, D6 | LED | LED_0805_2012Metric_Pad1.15x1.40mm_HandSolder | 3 | ~70
9 |  |  | U1 | ESP-13-WROOM-02 | ESP-WROOM-02 | 1 | >100
10 | ✓ |  | U2 | SN74AHCT125 | SOIC-14_3.9x8.7mm_P1.27mm | 1 | ~60
11 |  |  | U3 | LM1117-3.3 | SOT-223-3_TabPin2 | 1 | ~30
12 |  |  | F2, F3, F4 | Fuse | Fuseholder_Cylinder-5x20mm_Wurth_WR-FSH_Horizontal | 3 | ~20
13 |  |  | F1 | Polyfuse | Fuse_1812_4532Metric_Pad1.30x3.40mm_HandSolder | 1 | ~15
14 |  |  | SW1 | Reset | SW_SPST_GULLWING | 1
15 |  |  | G***, G*** | LOGO | mcqn-logo-30mm | 2
16 |  |  | Q1 | NJT4031NT1G | SOT-223-3_TabPin2 | 1 | >50
17 |  |  | J1 | APA102 | PhoenixContact_MSTBVA_2,5_8-G-5,08_1x08_P5.08mm_Vertical | 1 | ~16
18 |  |  | J2 | WS2812 | PinHeader_1x03_P2.54mm_Vertical | 1
19 |  |  | J3 | Serial | PinHeader_1x06_P2.54mm_Vertical | 1
20 |  |  | P1, P2 | CONN_01X09 | PinSocket_1x09_P2.54mm_Vertical | 2
21 |  |  | P3 | ATX_Power_2x12_Connector | Molex_44206-0007_socket_(ATX_power) | 1

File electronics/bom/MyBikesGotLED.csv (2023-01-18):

Id | Designator | Footprint | Quantity | Designation | Supplier and ref
1 | J3 | PinHeader_1x03_P2.54mm_Horizontal | 1 | WS2812
2 | R4,R26 | R_0603_1608Metric_Pad0.98x0.95mm_HandSolder | 2 | R10K
3 | C6,C8 | C_1812_4532Metric_Pad1.57x3.40mm_HandSolder | 2 | 22uF X5R
4 | C5 | C_0603_1608Metric_Pad1.08x0.95mm_HandSolder | 1 | 100uF
5 | R9 | R_0603_1608Metric_Pad0.98x0.95mm_HandSolder | 1 | 10K
6 | R2,R3 | R_0603_1608Metric_Pad0.98x0.95mm_HandSolder | 2 | 5.1K
7 | U2 | SOIC-14_3.9x8.7mm_P1.27mm | 1 | SN74AHCT125
8 | R10 | R_0603_1608Metric_Pad0.98x0.95mm_HandSolder | 1 | 90K
9 | P1,P2 | PinHeader_1x01_P2.54mm_Vertical | 2 | Conn_01x01
10 | U1 | Diodes_SO-8EP | 1 | FP6276B Boost_Convertor
11 | F1,F2 | Fuse_1812_4532Metric_Pad1.30x3.40mm_HandSolder | 2 | Polyfuse
12 | T1,T2 | TestPoint_Pad_D2.0mm | 2 | CONN_01X01
13 | SW1 | SW_SPST_GULLWING | 1 | Reset
14 | R1 | R_0603_1608Metric_Pad0.98x0.95mm_HandSolder | 1 | 1M
15 | 5V_T1,Clk_T1,Data_T1 | TestPoint_Pad_D2.0mm | 3 | Conn_01x01
16 | C3 | C_0603_1608Metric_Pad1.08x0.95mm_HandSolder | 1 | 1nF
17 | C4,C1 | C_1812_4532Metric_Pad1.57x3.40mm_HandSolder | 2 | 22uF
18 | J1 | USB_C_Receptacle_Amphenol_12401610E4-2A | 1 | USB_C_Receptacle
19 | L1 | L_7.3x7.3_H3.5 | 1 | 3.3uH
20 | L2 | L_12x12mm_H6mm | 1 | 1.5uH
21 | R12,R15,R16 | R_0603_1608Metric_Pad0.98x0.95mm_HandSolder | 3 | R560
22 | R13,R14,R17 | R_0603_1608Metric_Pad0.98x0.95mm_HandSolder | 3 | R10k
23 | U4 | ESP-WROOM-02 | 1 | ESP-13-WROOM-02
24 | U5 | SSOP-10_3.9x4.9mm_P1.00mm | 1 | CN3791
25 | Q2 | SOT-23-6 | 1 | FS8205
26 | R6,R5 | R_0603_1608Metric_Pad0.98x0.95mm_HandSolder | 2 | 470R
27 | R18,R27 | R_0603_1608Metric_Pad0.98x0.95mm_HandSolder | 2 | R_Small
28 | SW2 | SW_CuK_OS102011MA1QN1_SPDT_Angled | 1 | ON/OFF
29 | C7,C16,C13 | C_0603_1608Metric_Pad1.08x0.95mm_HandSolder | 3 | 0.1uF
30 | J5,J6 | PinHeader_1x03_P2.54mm_Vertical | 2 | Conn_01x03
31 | D5,D6,D7 | D_SMF | 3 | D_Schottky
32 | J2 | OQ0412510000G | 1 | Conn_01x04
33 | R7 | R_0603_1608Metric_Pad0.98x0.95mm_HandSolder | 1 | 43K
34 | R8 | R_0603_1608Metric_Pad0.98x0.95mm_HandSolder | 1 | 73K
35 | J7 | OQ0212510000G | 1 | Solar Input
36 | JP4 | SolderJumper-2_P1.3mm_Bridged_RoundedPad1.0x1.5mm | 1 | Jumper_2_Bridged
37 | R28,R23 | R_0805_2012Metric_Pad1.20x1.40mm_HandSolder | 2 | Rcs
38 | C12 | C_0603_1608Metric_Pad1.08x0.95mm_HandSolder | 1 | 220nF
39 | J8 | PinHeader_1x02_P2.54mm_Vertical | 1 | Battery
40 | C14,C11 | C_0603_1608Metric_Pad1.08x0.95mm_HandSolder | 2 | 1uF
41 | D2,D1 | LED_0805_2012Metric_Pad1.15x1.40mm_HandSolder | 2 | LED
42 | R29,R25 | R_0603_1608Metric_Pad0.98x0.95mm_HandSolder | 2 | 100K
43 | R24 | R_0603_1608Metric_Pad0.98x0.95mm_HandSolder | 1 | 100R
44 | D8 | D_SOD-323 | 1 | MM3Z4V3ST1G
45 | J4 | PinHeader_1x06_P2.54mm_Vertical | 1 | Serial
46 | R22,R21 | R_0805_2012Metric_Pad1.20x1.40mm_HandSolder | 2 | R_Small
47 | D4 | LED_0805_2012Metric_Pad1.15x1.40mm_HandSolder | 1 | LED Red
48 | R20 | R_0603_1608Metric_Pad0.98x0.95mm_HandSolder | 1 | 320K
49 | Q3 | SOT-23 | 1 | JSM2302
50 | C10,C15 | C_1206_3216Metric_Pad1.33x1.80mm_HandSolder | 2 | 10uF 50V
51 | D3 | LED_0805_2012Metric_Pad1.15x1.40mm_HandSolder | 1 | LED Green
52 | L3 | L_12x12mm_H6mm | 1 | 100uH 2.5A
53 | R19 | R_0603_1608Metric_Pad0.98x0.95mm_HandSolder | 1 | 120R
54 | Q4,Q1 | SOT-23 | 2 | P-channel 30V 4A MOSfet
55 | BT1 | JST_PH_S2B-PH-SM4-TB_1x02-1MP_P2.00mm_Horizontal | 1 | Battery_Cell
56 | JP5 | SolderJumper-2_P1.3mm_Bridged2Bar_RoundedPad1.0x1.5mm | 1 | Test Point
57 | JP1 | SolderJumper-2_P1.3mm_Open_RoundedPad1.0x1.5mm | 1 | FTDI_PWR
58 | P3,P4 | PinSocket_1x09_P2.54mm_Vertical | 2 | CONN_01X09
59 | R11 | R_0603_1608Metric_Pad0.98x0.95mm_HandSolder | 1 | 20K
60 | JP2 | SolderJumper-2_P1.3mm_Open_RoundedPad1.0x1.5mm | 1 | p16 EN
61 | JP6 | SolderJumper-2_P1.3mm_Open_RoundedPad1.0x1.5mm | 1 | Jumper_on
62 | JP3 | SolderJumper-2_P1.3mm_Open_RoundedPad1.0x1.5mm | 1 | P5 EN
63 | U3 | SOT-23-5 | 1 | RT8097B
64 | U6 | SOT-23-6_Handsoldering | 1 | FS312F-G
65 | C9 | C_0603_1608Metric_Pad1.08x0.95mm_HandSolder | 1 | C47nF
66 | G*** | mcqn-logo-20mm | 1 | LOGO

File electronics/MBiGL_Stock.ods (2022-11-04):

null | Sourced | Placed | References | Value | Footprint | Quantity |  | Stock
1 |  |  | C3, C4, C6, C8 | 22uF X5R | C_1812_4532Metric_Pad1.57x3.40mm_HandSolder | 4 |  | 48
2 |  |  | C1 | 0.1uF | C_0603_1608Metric_Pad1.08x0.95mm_HandSolder | 1 |  | 60
3 |  |  | C2 | C47nF | C_0603_1608Metric_Pad1.05x0.95mm_HandSolder | 1 |  | 15 | 15
4 |  |  | C5 | 0.1uF | C_0603_1608Metric_Pad1.05x0.95mm_HandSolder | 1 |  | see C1
5 |  |  | C7 | 470uF | C_Elec_10x10.2 | 1 |  | 20
6 |  |  | R1, R2, R10 | R10k | R_0603_1608Metric_Pad1.05x0.95mm_HandSolder | 3 |  | 45
7 |  |  | R7, R8, R9 | R560 | R_0603_1608Metric_Pad1.05x0.95mm_HandSolder | 3 |  | 50
8 |  |  | R3, R4 | 470R | R_0603_1608Metric_Pad1.05x0.95mm_HandSolder | 2 |  | 90
9 |  |  | R5, R14 | 1K | R_0603_1608Metric_Pad0.98x0.95mm_HandSolder | 2 |  | 29
10 |  |  | R6, R17 | 100k | R_0603_1608Metric_Pad0.98x0.95mm_HandSolder | 2 |  | 26
11 |  |  | R12, R18 | R10K | R_0603_1608Metric_Pad0.98x0.95mm_HandSolder | 2 |  | see R1
12 |  |  | R11 | 100R | R_0603_1608Metric_Pad0.98x0.95mm_HandSolder | 1 |  | 15
13 |  |  | R13 | 7K5 | R_0603_1608Metric_Pad0.98x0.95mm_HandSolder | 1 |  | 14
14 |  |  | R15 | 90K | R_0603_1608Metric_Pad0.98x0.95mm_HandSolder | 1 |  | 14 | 20
15 |  |  | R16 | 20K | R_0603_1608Metric_Pad0.98x0.95mm_HandSolder | 1 |  | 14
16 |  |  | L1 | 22uH | L_7.3x7.3_H4.5 | 1
17 |  |  | L2 | 1.5uH | L_12x12mm_H6mm | 1 |  | 15
18 |  |  | D5, D6 | LED | LED_SMD_WL-SMSW_side-emitting | 2
19 |  |  | D1 | D_Schottky_Small | D_SMD_MicroDiode_MDD | 1 |  | 40
20 |  |  | U1 | ESP-13-WROOM-02 | ESP-WROOM-02 | 1 |  | 100 | +
21 |  |  | U2 | SN74AHCT125 | SOIC-14_3.9x8.7mm_P1.27mm | 1 |  | 80
22 |  |  | U3 | FS312F-G | SOT-23-6_Handsoldering | 1
23 |  |  | U4 | MT3608 | SOT-23-6 | 1 |  | 14
24 |  |  | U5 | RT8097B | SOT-23-5 | 1 |  | 15
25 |  |  | F1, F2 | Polyfuse | Fuse_1812_4532Metric_Pad1.30x3.40mm_HandSolder | 2 | g | 40
26 |  |  | SW1 | Reset | SW_SPST_GULLWING | 1 |  | 20
27 |  |  | SW2 | ON/OFF | SW_CuK_OS102011MA1QN1_SPDT_Angled | 1 |  | 15
28 |  |  | G***, G*** | LOGO | mcqn-logo-30mm | 2 |  | ok
29 |  |  | Q1 | FS8205 | SOT-23-6 | 1 |  | 15
30 |  |  | Q2 | JSM2302 | SOT-23 | 1 |  | 25
31 |  |  | J6, J7 | Conn_01x03 | PinHeader_1x03_P2.54mm_Vertical | 2 |  | ok
32 |  |  | J1 | Battery | JST_PH_S2B-PH-SM4-TB_1x02-1MP_P2.00mm_Horizontal | 1 |  | 15
33 |  |  | J2 | WS2812 | PinHeader_1x03_P2.54mm_Horizontal | 1 |  | ok
34 |  |  | J3 | Serial | PinHeader_1x06_P2.54mm_Vertical | 1 |  | ok
35 |  |  | J4 | Battery_Test_Points | PinSocket_1x02_P2.54mm_Vertical | 1 |  | ok
36 |  |  | J5 | Conn_01x04 | PhoenixContact_MSTBA_2,5_4-G-5,08_1x04_P5.08mm_Horizontal | 1 |  | ok
37 |  |  | P1, P2 | CONN_01X09 | PinSocket_1x09_P2.54mm_Vertical | 2 |  | ok

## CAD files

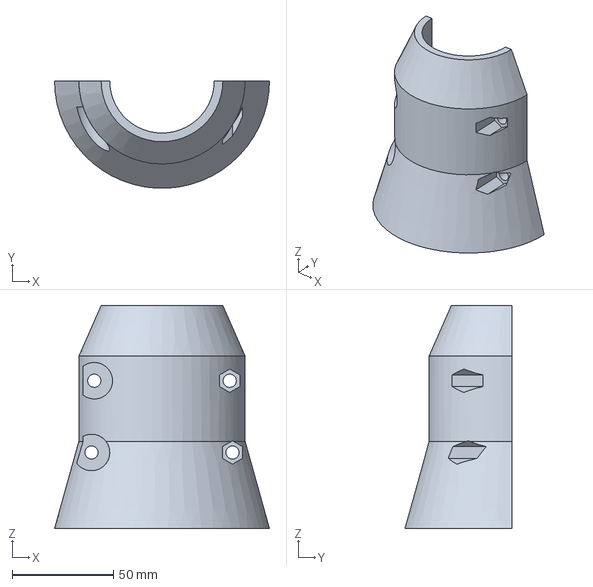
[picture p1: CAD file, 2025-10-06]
my-bollards-got-led/physical/base-sleeve.FCStd
106.0 x 52.9 x 110.0 mm

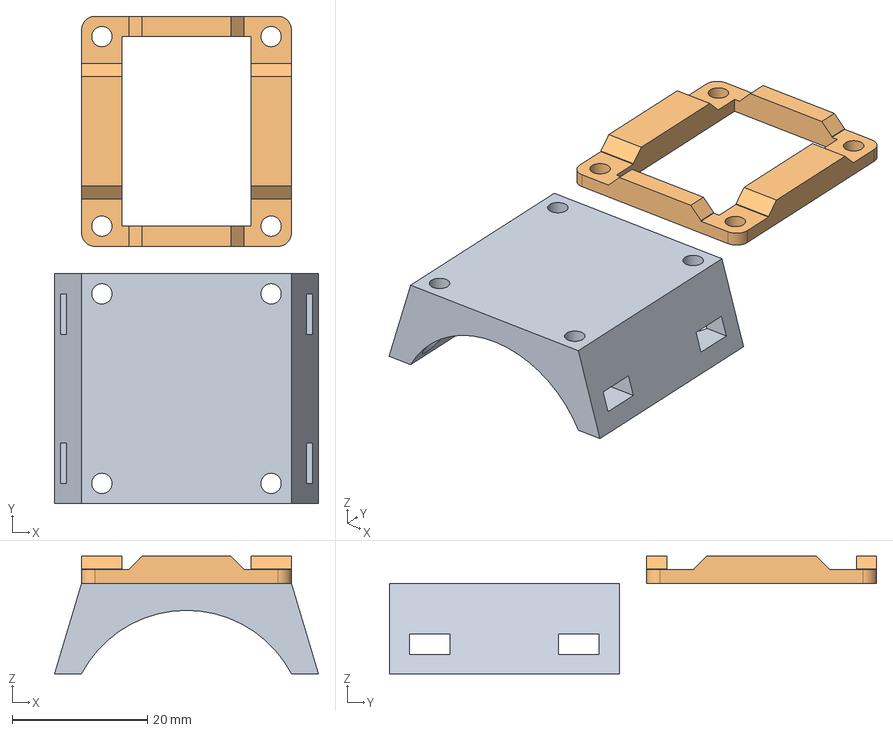
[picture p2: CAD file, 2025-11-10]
physical/HandlebarButtonMount.FCStd
39.0 x 72.0 x 17.4 mm
Bottom
Top

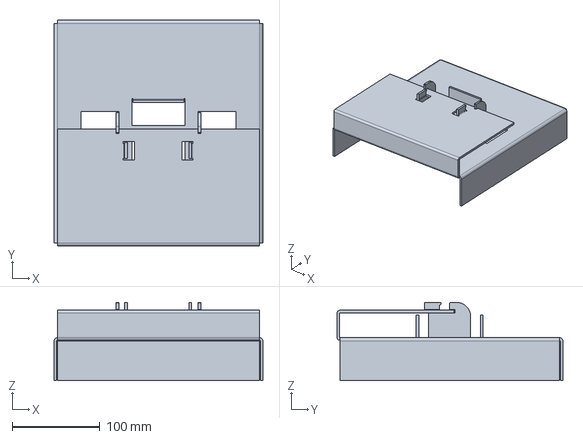
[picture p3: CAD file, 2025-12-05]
physical/packaging/MBiGL-BoxInsert.FCStd
238.0 x 257.1 x 89.2 mm

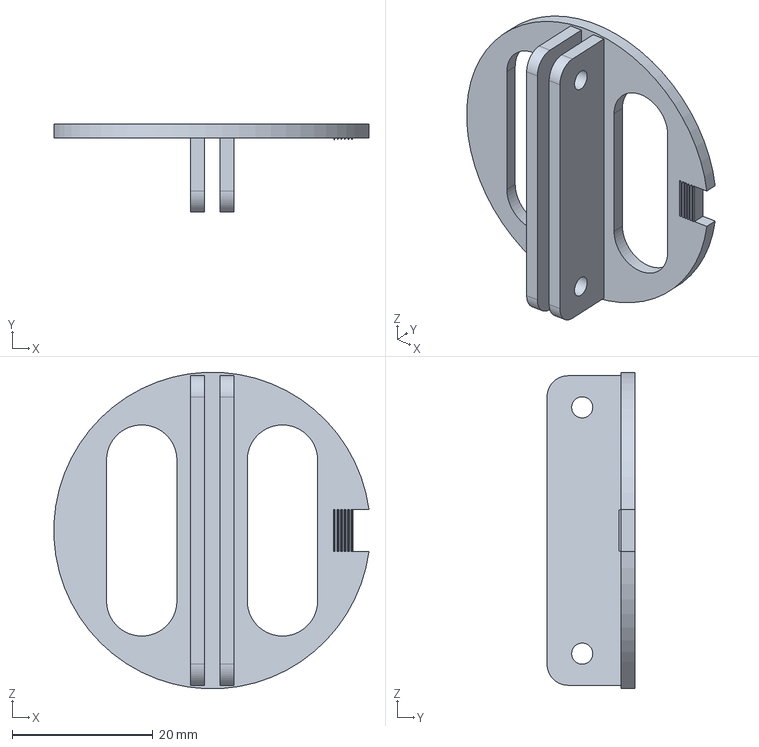
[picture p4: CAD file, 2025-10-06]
my-bollards-got-led/physical/lastmile_boardToBattery.FCStd
44.8 x 12.5 x 45.0 mm

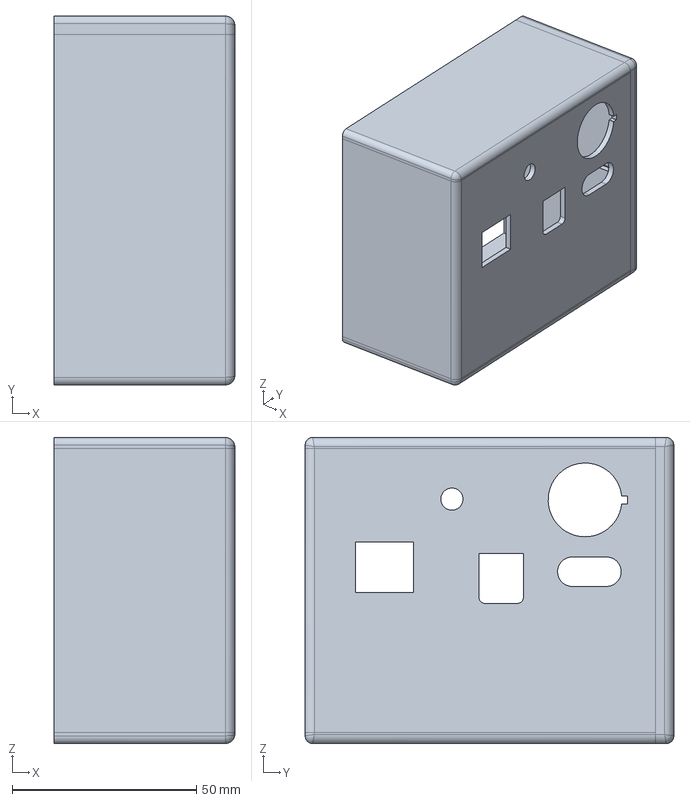
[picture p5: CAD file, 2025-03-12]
physical/MBiGL_soundreactive.FCStd
49.0 x 100.0 x 83.0 mm

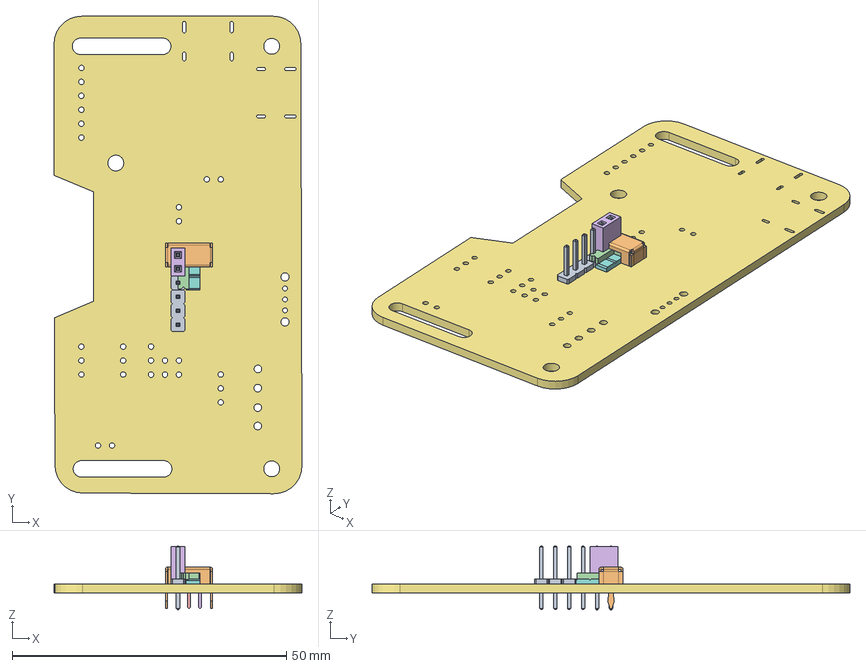
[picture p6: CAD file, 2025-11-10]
physical/packaging/MyBikesGotLED-PCB.FCStd
45.2 x 87.0 x 11.6 mm
R_0603_1608Metric
R_0402_1005Metric
R_0402_1005Metric002
R_0402_1005Metric004
PinHeader_1x03_P254mm_Vertical
PinHeader_1x03_P254mm_Vertical001
LED_0805_2012Metric
PinHeader_1x03_P254mm_Horizontal
PinHeader_1x01_P254mm_Vertical
R_0603_1608Metric002
C_0603_1608Metric
C_0805_2012Metric
C_0402_1005Metric
C_0603_1608Metric002
R_0603_1608Metric004
R_0603_1608Metric006
PinHeader_1x03_P254mm_Vertical002
SW_Slide_SPDT_Angled_CK_OS102011MA1Q
SW_Slide_SPDT_Angled_CK_OS102011MA1Q001
SW_Slide_SPDT_Angled_CK_OS102011MA1Q002
SW_Slide_SPDT_Angled_CK_OS102011MA1Q003
SW_Slide_SPDT_Angled_CK_OS102011MA1Q004
SW_Slide_SPDT_Angled_CK_OS102011MA1Q005
R_0603_1608Metric008
C_0603_1608Metric004
R_0603_1608Metric010
LED_0805_2012Metric002
R_0603_1608Metric012
R_0402_1005Metric006
PinSocket_1x02_P2.54mm_Vertical
PinHeader_1x03_P254mm_Vertical003
R_0402_1005Metric008
R_0402_1005Metric010
PinSocket_1x02_P2.54mm_Vertical002
C_0402_1005Metric002
LED_0805_2012Metric004
C_0402_1005Metric004
C_0402_1005Metric006
PinSocket_1x02_P2.54mm_Vertical004
R_0603_1608Metric014
R_0603_1608Metric016
R_0402_1005Metric012
SOT_23
LED_0805_2012Metric006
C_0603_1608Metric006
R_0402_1005Metric014
R_0603_1608Metric018
C_0805_2012Metric002
PinHeader_1x06_P254mm_Vertical
C_0402_1005Metric008
C_0603_1608Metric008
LED_0805_2012Metric008
HTSSOP_14_1EP_44x5mm_P065mm_EP34x5mm_Mask3x31mm
R_0603_1608Metric020
R_0603_1608Metric022
R_0603_1608Metric024
R_0603_1608Metric026
C_0603_1608Metric010
R_0603_1608Metric028
SOT_23_5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

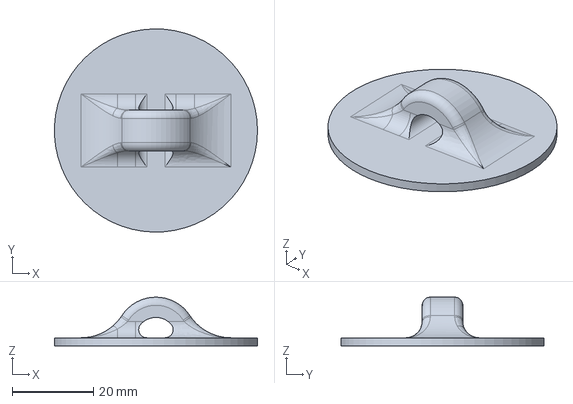
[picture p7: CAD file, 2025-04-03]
my-bollards-got-led/physical/lastmile_tophook.FCStd
50.0 x 50.0 x 12.0 mm

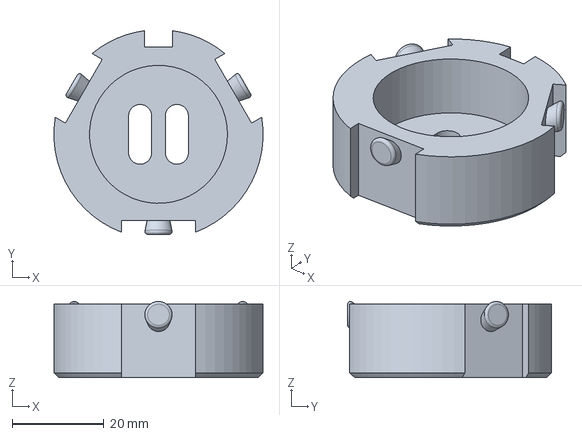
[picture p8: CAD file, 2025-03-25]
my-bollards-got-led/physical/LED-tensioner-top.FCStd
45.4 x 44.3 x 16.5 mm

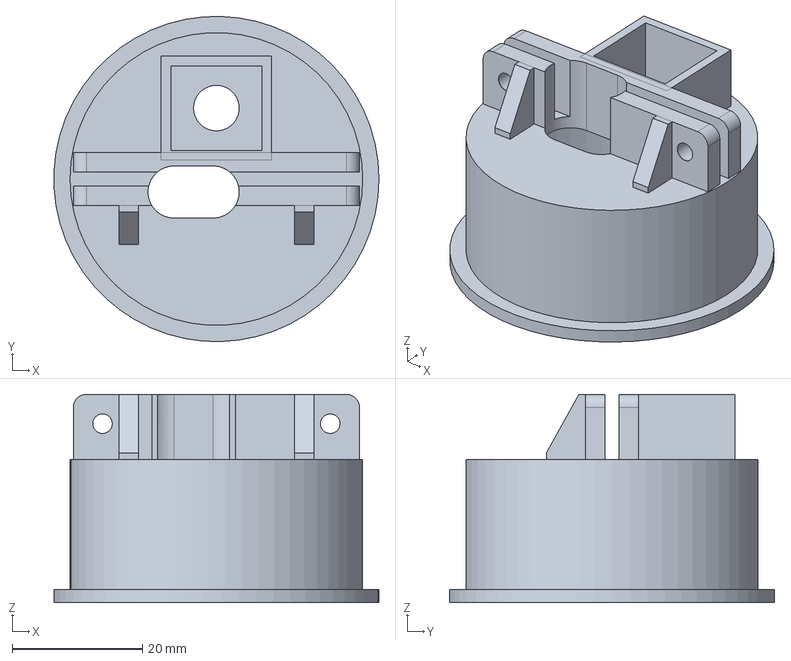
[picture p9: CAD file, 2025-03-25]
my-bollards-got-led/physical/lastmile_boardBottomPlug.FCStd
50.0 x 50.0 x 32.0 mm

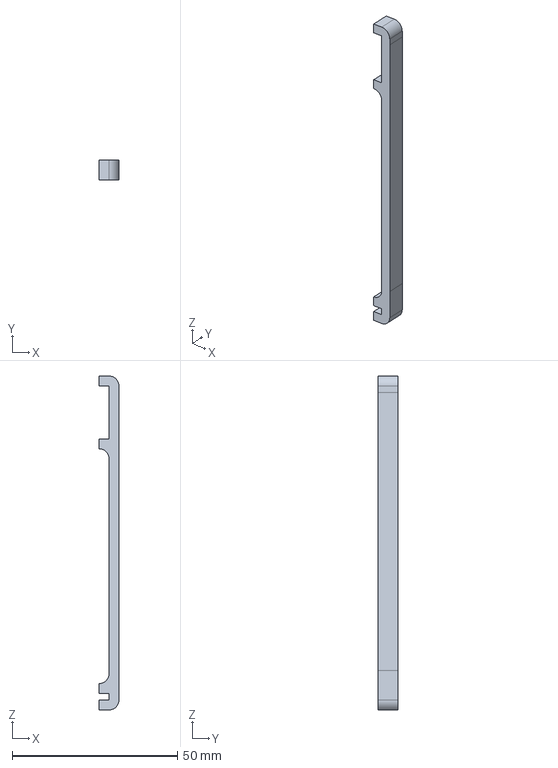
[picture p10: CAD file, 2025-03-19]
my-bollards-got-led/physical/lastmile_boardBrace.FCStd
6.00 x 6.00 x 101.0 mm

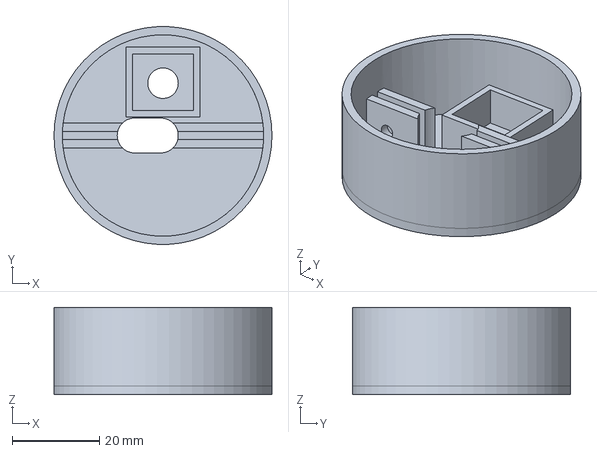
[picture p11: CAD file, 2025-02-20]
my-bollards-got-led/physical/lastmile_boardHolder.FCStd
50.0 x 49.9 x 20.0 mm

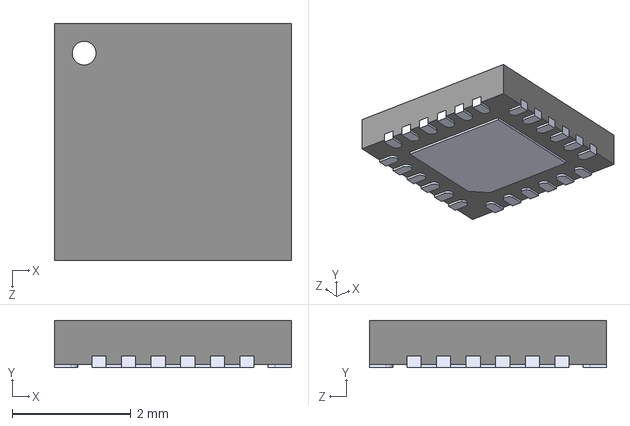
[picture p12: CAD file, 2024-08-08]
electronics/BQ25895MRTWR.step
4.00 x 0.8 x 4.00 mm

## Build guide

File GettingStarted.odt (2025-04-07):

My Bike’s Got LED Controller Board

mcqn.com/ibal234/

Setting Up

1. Using velcro ties fix the lights to your frame, making sure the green plug reaches to where you are mounting the My Baby’s got LED board to your bike.

Getting Started

2. Connect your lights to the My Bike’s Got LED controller with the green terminal block.
3. Plug your Battery pack into the white JST connector on the side of the My Bike’s Got LED controller board.
4. Turn on the board with the On/Off switch. The “Charging” lights should illuminate on the controller board; the first 30 LEDs on your LED strip will light up amber.
5. It will create a new WiFi network called “WLED-AP” with a password of “wled1234”. Connect to that with your phone or computer.
6. You’ll be redirected to the WLED welcome page, from there you can control the lights directly

Connecting the Controller to Your Network

It might be more convenient for you to connect the board to your local wifi while you are setting it up. Of course when you are out on your bike you won’t have this option but you will still be able to connect via the access point as described above.

1. Run through the steps in “Getting Started” above.
2. When you get to the WLED welcome page, choose the “WiFi Settings” option.
3. Enter the details of your WiFi so that it can connect to your network (then you’ll be able to control it from any computer/phone on your network) but DO NOT click on save just yet!
4. Find the mDNS setting. You might want to give your controller board a better mDNS name so it’s easier to connect to from your network. At the very least you should make a note of the name, as you’ll need it in a moment.
5. Now you can save the settings by clicking “Save & Connect”.
6. Connect back to your network with your phone/laptop (usually this happens automatically when the controller board turns off the WLED-AP network.
7. In a web browser, go to the name that you made a note of in step 4. If you changed the mDNS name you will need to reset the board by pressing the pink reset button for the new name to take effect.
8. Now you can control the lights as before.

Status Lights

The My Bike’s Got LED controller board has four yellow status lights. These will either show the status of the battery when you first switch the board on, or the charging status if a USB cable is connected.

Creating a preset

To change the default light pattern when you first turn on your lights you will need to create a preset.

1. Using the ‘Colors” and “effects” settings create the light pattern you would like as the default.
2. Click on the presets menu, and then “+ preset”
3. Make sure “Use current state” is ticked and click save. NB remember the ID number you are saving this preset to.
4. Click on the “Config” menu and select “LED Preferences”. Scroll down to find “Defaults”. In “Apply preset _ at boot” put in the ID number from step 3. Click save.
5. Your board will now default to this preset when it is powered up.

Factory Reset

To perform a factory reset of your device connect to the WLED controller interface as described above.

Click on the ‘Config’ button and select ‘Security and updates’

Tick the ‘Factory reset’ checkbox and press ‘Save and reboot’

More Information

The controller board uses an ESP32-C3 mini module.

Pins 0,1,3,4 and 10 are available via J10 as gpio pins.

Pins 03 and 04 can optionally be level shifted to 5V if additional data outputs are required. This is achieved by soldering the labelled jumper at the bottom left of the board.

If you would like to included an audio input so that the lights respond to sounds there is a lot of information included in the WLED documentation (https://kno.wled.ge/advanced/audio-reactive/).

We have used the INMP441 microphone with the following GPIO:

SD - pin 10

SCK - pin 0

WS - pin 1

L/R – pin 4

The PCM1808 digital analog convertor can be used if you want to use a line in, such as a 3.5mm jack. For this we used:

Bck = pin 0

Out = pin 3

LRC = pin 4

SCK = pin 0

The board is able to provide 2.5A for lights, the rated output for the convertor is 3.1A but some will be required for the proccessor.

There’s lots more information about the WLED software available at

https://kno.wled.ge/

If you have any other questions, drop us a line at info@mcqn.com.

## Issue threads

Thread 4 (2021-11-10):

Minimize area of the output loop on the 5V converter

amcewen, 2021-11-10:
Having watched https://www.youtube.com/watch?v=u-y1F_ymImk if the 5V boost circuit gets redesigned, we should aim to minimize the output loop (round the diode, output capacitor and switch in the control IC) to reduce the EMC noise.

Similarly on the input side of the 3V3 convertor

amcewen, 2022-07-04:
https://www.youtube.com/watch?v=_epMv9yvOxY also has good notes on EMC with SMPS.  Might be worth looking at:
* Making input caps symmetric, and including small (100nF) decoupling caps
* PGND on the IC is generally best for wicking away heat, as it will be connected to the h-bridge in the chip
* Removing the copper from under the inductor will improve its performance and reduce generated heat, but it could also make the EMC worse conducted emissions (but better for radiated emissions).  Keeping a ground plane under the inductor might be a reasonable middle ground (if the heat issue in #3 isn't affected)
* Semi-shielded inductors might actually work better than shielded ones for EMC, it just depends on the scenario and the inductors.
* Connect the startup winding for the inductor to the switching side, for better EMC (generally can be seen with a dot on the case)

https://www.youtube.com/watch?v=5Or3Z_BpDXY also has some good suggestions for layout, and uses *lots* of vias for better thermal performance

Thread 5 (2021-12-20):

Find an enclosure to hold a board and battery

amcewen, 2021-12-20:
We need a good way to fix the board onto a bike.

amcewen, 2022-01-12:
The neoprene phone case I've been dogfooding on my bike isn't completely waterproof—in the torrential rain last week it got saturated, which caused the lights to stop working.  Once it had dried out it was okay, but didn't handle the wet.

(It's not the preferred option anyway, but useful to know)

amcewen, 2025-01-03:
The saddle bags we used for the initial v1 kits seem to work pretty well (and we haven't had any complaints from the #FolkRidingBikes members who've been using them for a couple of seasons now).

Closed 2025-01-03.

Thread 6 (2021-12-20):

Find process for connecting wires to the light strips

amcewen, 2021-12-20:
The WS2812B lights come in reels of 5m.  A bike will need ~1/3rd of that, so there'll be two strips which will need headers.

The system used for the Geometric Lights would work, but is quite labour-intensive.  It'd be nice to find a simpler option.

amcewen, 2022-05-16:
We've  got some supposedly clip-in connectors, so we should work out how well they work.

huffeec, 2022-10-21:
The clips seem to be 10mm and the strips 12mm.
I've tried lots of methods to connect these. The best approach so far is to trim away the sides of the sheath so that the strip fits into the clip and putting a small piece of double sided foam tape on the top of the strip to provide enough thickness that the pins in the clip and puncture the bottom plastic. I also had more success taking the clip completely apart so that it's easier to seat the strip and then adding the top of the clip.

amcewen, 2022-10-31:
For the batch we prepped for the Katumba Halloween Carnival we soldered wires to the strips and sealed them with 12.7mm ID glue-lined heatshrink.  Then the other end could be cut to length and a cap glued on with rubber cement.

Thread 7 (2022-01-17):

Add-on: A handlebar button for controlling the lights

amcewen, 2022-01-17:
It would be nice to be able to change colours and/or patterns without needing your phone.

A button mounted on the handlebars seems the most sensible approach.  There's support in WLED for a button, wired between pin 0 and ground.

Could it be designed to allow injection-moulding with recycled plastic at Precious Plastics Lancaster?  Maybe old inner-tubes could be re-used as the gasket for waterproofing?

amcewen, 2022-01-17:
Got a first pass built of this - https://twitter.com/amcewen/status/1481289092725936134

Needed to modify `button.cpp` in WLED so it cycles through the presets rather than just switching to one of them.  That's a rather hacky proof-of-concept at the moment, will need work to integrate it cleanly; however, it worked nicely and it's useful to be able to switch between presets.

The button works, but needs improvement:
* The opening to get to the button needs to be bigger—it's fine with just a finger, but once you're wearing gloves it's hard to activate
* It's very fiddly to assemble
* The ends of the inner tube don't seal, so it's only splash-proof rather than waterproof at present

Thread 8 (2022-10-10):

Connect 2 additional gpio pins to level shifter

huffeec, 2022-10-10:
Include breakable jumpers so it can be turned off

huffeec, 2022-10-12:
V2 board includes access to pins IO5 and IO16

JackiePease, 2022-10-27:
This is the [link to multi-strip support info](https://kno.wled.ge/features/multi-strip/).
It says that "It is highly recommended to use two specific LED pins, GPIO1 (TX) and GPIO2 (D4), since they allow for hardware driving." although others can be used with the bitbang method.

huffeec, 2022-10-31:
That's useful to see. Given that, "It is highly recommended to use an ESP32 when using more than 1 output." is this something we need to be too concerned with while we're using 8266's?

huffeec, 2022-11-01:
Checking this IO2 is already available as the led_data is there value in breaking out more for this rev?

amcewen, 2025-01-03:
This has been folded into the v2 board updates.

Closed 2025-01-03.

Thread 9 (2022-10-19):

Stock for new boards

huffeec, 2022-10-19:
There are 15 unpopulated v1 pcbs
There are enough components in stock to populate 9 boards

To populate fifteen boards the following additional components are needed
C3, C4, C6, C8 - 22uF (1812) Short by 12
~~R5, R14 - 1K (0603) Short by 1~~
~~R1, R2, R10 - 10K (0603) short by 30~~
R13 -7K5 (0603) short by 1
R15 - 90K (0603) short by 1
R16 - 20K (0603) short by 1
U4 - MT3608 SOT-23-6 short by 1

I've not managed to find any of the 22uH inductors (L1) yet or the battery protection IC(U3) but suspect there are as many remaining as the other inductor (15)?

L1 - 22uH
~~U3 - FS312F-G~~

huffeec, 2022-10-19:
[Sheet with full stock list of components](https://github.com/mcqn/my-bikes-got-led/blob/main/electronics/MBiGL_Stock.ods)

amcewen, 2022-10-19:
Parts ordered to make up the shortfall, apart from U4 as Farnell don't stock it.

amcewen, 2022-10-21:
Parts arrived yesterday.  I think we'll leave U4 until we're ordering more parts from China.

Closed 2022-10-21.

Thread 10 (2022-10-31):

Create a "Getting Started" guide for the kits

amcewen, 2022-10-31:
We need a My Bike's Got LED version of [the Getting Started guide](https://github.com/mcqn/my-babys-got-led/blob/main/GettingStarted.odt).

Should probably recommend:
* Setting the number of LEDs
* Creating a preset
* Configuring the system to choose the preset at startup
* Instructions on how to fit the kit to a bike

huffeec, 2022-11-16:
I've copied over the Getting started guide and added a basic 'Setting up' section explaining how to attach the lights.

huffeec, 2025-04-07:
completed by #39

Closed 2025-04-07.

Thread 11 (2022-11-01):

Charger circuit for V2 boards?

huffeec, 2022-11-01:
Add a battery charger circuit to V2

USbc connector (will require moving Network and Wifi lights) so that it is on the edge
Charging and charged status lights

What happens when a charging power supply is connected and the lights are on?

Looking inital at the [CN3791 IC ](https://datasheetspdf.com/pdf-file/1257610/CONSONANCE/CN3791/1)used in the solar circuit.

Closed 2022-11-09.

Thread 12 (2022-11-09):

v2 boards updates

huffeec, 2022-11-09:
Changes for V2

Update the light connector to use [https://uk.farnell.com/amphenol-anytek/oq0412510000g/terminal-block-r-a-header-4way/dp/3810182](https://uk.farnell.com/amphenol-anytek/oq0412510000g/terminal-block-r-a-header-4way/dp/3810182)

Added charging circuit from [Tactile Electronics](https://github.com/Tactile-electronics/windmill-electronics)

Added connection to fix #2 added wire is between FS312F-G (U3) pin 2 and JSM2302 (Q2) pin 3

reduced board height from 90mm to 82mm

amcewen, 2022-11-17:
Reviewed the changes:
* We should use thicker traces for the power circuits
* The `U3` and `Q1` (but not `Q2`) protection circuit should probably move to just by the `BT1` and `J9` area, so it's protecting the battery, rather than after the charging side
* Can the regulators - both 5V and 3V3 - cope with 5V as input, given that the charging circuit will supply it.  Might need to provide some protection for the solar input too, as that could provide even higher voltages :worried:   Actually, reading the datasheet for the 5V boost chip, its maximum input voltage is 4.5V, so we might need protection for just USB, never mind higher solar voltages.  Not sure how useful the running-while-charging approach will be, given the current the LEDs can draw will often be beyond what the USB will provide, but it'll be good to try (and I suppose if nothing else, maybe it'll just power the lights so less is drawn from the battery).  A [zener diode regulator circuit](https://wiraelectrical.com/zener-diode-voltage-regulator/) might be enough?
* Checking USB-C connector availability, I see [Farnell has them](https://uk.farnell.com/amphenol-fci/12401610e4-2a/usb-conn-3-1-type-c-rcpt-smd/dp/3367461) which is good (might be able to find cheaper, but I wanted to check they were readily available)
* I wonder if `L2` and `L3` need to be so *physically* big?  Smaller ones would free up a bit of board space, but it's probably not worth changing unless we end up revisiting the area where they are and some more room would be handy...
* There are no mounting holes on the PCB at present.  I think that's because they're easy to end up deleting when you import a new schematic as they're footprints that don't have an associated symbol.  Similarly with the assorted logos: WEEE, RoHS, OSHWA, etc.  There are "Graphic" symbols it seems, which we should add to the schematic so they'll pull in the right logos and make sure they don't get lost.  Seems there are "Mechanical" ones too, so we can use those to add the mounting holes.

huffeec, 2022-12-12:
Above updates addressed in newest commit.
The ERC and DRC have both been run, akaik the remaining errors are not significant.

amcewen, 2022-12-20:
* We should check the battery usermod in case we need to tweak the battery->ADC circuitry
* Revision number needs updating
* Can we squeeze on a smaller MCQN logo in the corner by the FTDI connector?
* Would be good to label the jumpers, but not sure if there's space
* Do we need any thermal vias on the boost or charging circuit?

huffeec, 2022-12-21:
The latest update has points 2, 4 and 5** complete.
** I added vias and extra copper around the components. There wasn't much of a clue about layout in the datasheet so this is all fairly arbitrary and could use a sense check.

1 Short answer to this is I'm not sure. It feel like this must need to be a potential divider circuit to bring down the voltage to ~3 max. Which would suggest we need a 2nd resistor in series with R20. Related to this R28 value is still tbc and may make the second resistor redundant in the battery monitor circuit.

3 Adding logos needs to be easier in kicad but I'm sure I can squeeze something in here.

amcewen, 2023-01-18:
Latest revision looks on the brink of good to go.  Can we add the MCQN, WEEE, and RoHS logos onto the underside of the PCB.  Then if you can export the Gerbers we can kick off a production run :grin:

huffeec, 2023-01-18:
Output file added with Gerbers

huffeec, 2023-02-08:
First boards populated.
Bugs:

Track from Q3 pin 3 to Q2 pin 1 should have a junction where it crosses the -Batt line
(Temp fix is a wire from jp6 to -Batt (bt1)
Remove R28?
Some board hum and warming of L2 with 100 lights running, needs further investigation

huffeec, 2023-02-13:
The fix above q3 p3 to q2 p1 will work with battery power but not by usb. The switch circuit still isn't working.
While this appears to work I think this is only related to the solution

Have tried removing this wire and instead connecting q2 p3 to u6 p6
D4 lights with usb but no other activity
Nothing if powered by battery

It appears the protection IC is still where the error is. Currently Q2 is not operating, OD low/OC high and the CS (p2) path is incorrect. (This should probably route to GNG (p6)

Next steps
[Confirm CS path from datasheet](https://www.ic-fortune.com/upload/Download/FS312F-G-DS-12_EN.pdf)

Split the sheets into modular components
Battery + protection
Charging
Boost conversion
Level shifting
ESP

huffeec, 2023-02-15:
Potential issues seen when creating a more modular schematic.

The Battery Mod addition uses a PD between Batt+ and Gnd to provide the A0 input. This could explain why the switch is being bypassed?
The 1k resistor on the FS312 between CS and Gnd is missing

amcewen, 2023-02-22:
We should check whether the charging circuit ever gets to "done", given the Tactile Electronics board we've cribbed it from [always shows the "charging" LED](https://github.com/Tactile-electronics/windmill-electronics/issues/13)

amcewen, 2023-06-07:
Hopefully we'll be able to use an updated version of the Tactile Electronics board, but if we haven't solved it by July then we should look at switching to just a USB-charging option for the v2 boards (and we can add solar and/or dynamo charging in the future)

amcewen, 2023-11-23:
I'm wondering, although it'll be 50p or so more expensive on the BoM, if we should switch to [this TI combined charging and boost converter chip](https://www.ti.com/lit/ds/symlink/bq25895m.pdf) particularly because that can do faster charging from USB and will provide up to 3A of 5V

amcewen, 2025-01-03:
This has been superseded by #20

Closed 2025-01-03.

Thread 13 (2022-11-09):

Board reworking

huffeec, 2022-11-09:
Of the remaining 8 V1 boards;

1 is working and running WLED
2 need the firmware flashing **
5 need further investigation

amcewen, 2022-11-19:
Had a look at some more of the boards today.
* One with no power to the ESP had the 3V3 fuse only fully soldered at one side, and the inductor was similarly only soldered down on one side.  Now it seems to be functioning okay - I've put code on it and checked the AP is responding, but didn't have LEDs to hand to test it fully
* One with no comms to the ESP had the reset button not soldered down properly.  Soldering that up seems to have fixed things - not completely sure why, as it shouldn't have affected anything.  Beforehand I was receiving data from it over serial, but didn't seem to be able to send any data to it.  Now has code uploaded fine and the AP checked.  Needs testing fully with LEDs.
* The one with code but no AP doesn't seem to be booting up correctly.  I only ever get the same boot message, whereas I should be able to put it in programming mode by grounding pin `0` (which would give a different boot mode message).  I tried resoldering the resistors which should set some of that, but it hasn't made any difference.  Haven't spent lots of time on it, so we should check the docs and the connections on the ESP accordingly.

amcewen, 2022-11-25:
Checked the `boot mode` messages for the third board listed above.  It was consistently coming up with `boot mode:(1,0)`, which *is* programming mode.  For a "normal" boot the first digit would be `3`.  Pin `0` was permanently shorted to `GND`.  Some flux and heat on the `0` and `GND` pair cleared that up so it's working now.

huffeec, 2022-12-14:
Two more boards added to the OK pile today with new  U5 step down convertors (3v3)

amcewen, 2023-02-22:
Have we rescued all these boards now?  (Or at least all the ones worth trying to rescue?)  Can we close this off?

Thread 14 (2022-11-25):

Add voltage divider on battery voltage monitor

amcewen, 2022-11-25:
Checking over a board now I realised that the battery voltage is just wired to the analogue input of the ESP8266, so it's usually above 3.3V.  We haven't ever used it - it was more of a "this might be useful" addition, and there's a jumper to cut it, but we should check the voltages that the input can cope with and look at a voltage divider if it's out of range when the battery is 4.2V.

amcewen, 2022-12-07:
@huffeec pointed out there's already one resistor in the circuit for measuring battery voltage, which reminded me that I'd done some initial investigation of it when designing the v1 board.  The circuit we have now is the one that the [battery_status_basic](https://github.com/Aircoookie/WLED/tree/main/usermods/battery_status_basic) usermod suggests, so we should try enabling that and seeing what happens :grin:

huffeec, 2023-01-04:
Enabling the mod on a v1 board gives a reading of full battery, regardless of the actual status.This is a new link for the usermod info, it's changed above [https://github.com/Aircoookie/WLED/tree/main/usermods/Battery#useful-links](https://github.com/Aircoookie/WLED/tree/main/usermods/Battery#useful-links)

The [circuit described](https://arduinodiy.wordpress.com/2016/12/25/monitoring-lipo-battery-voltage-with-wemos-d1-minibattery-shield-and-thingspeak/) is based on a [Wemos D1](https://www.wemos.cc/en/latest/_static/files/sch_d1_mini_v3.0.0.pdf) which has an 'internal' divider circuit.

This isn't something currently on the mbigl board or internal to the ESP (afaik). [ESP Wroom 02](https://www.espressif.com/sites/default/files/documentation/0c-esp-wroom-02_datasheet_en.pdf)
The reversed zener diode (D8) is keeping the +Batt voltage in the range 0 - 4.3V

We need to be in the 0-1V range for the ADC so my (current) thinking is that that we will need a full potential divider around jp4 for the battery usermod to work.

I think...

amcewen, 2023-01-09:
Makes sense.  Reading through the circuit description, we'd want to have a voltage divider that's BatteryVoltage -> 320K resistor -> A0 -> 100K resistor -> Ground.

huffeec, 2023-01-11:
Added

Closed 2023-01-11.

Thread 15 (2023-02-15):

FS312f battery protection notes

huffeec, 2023-02-15:
Extension of #2 but opening a separate issue to record info about the [FS312f](https://www.ic-fortune.com/upload/Download/FS312F-G-DS-12_EN.pdf)

So these are notes rather than solutions at this stage

From data sheet (pg8)

"When a battery is connected to FS312F-G for the first time, it may not enter the normal condition (dischargeable may not be enabled). In this case, short the CS and VSS pins or connect to a charger to restore to the normal condition."

Normal operation (charge/discharge) occurs when two conditions are met
The first is fairly straightforward.
Vcc (pin 5) is in the range 2.9 - 4.25V

The second is that the CS input voltage (pin 2) is in the range
VCH<VCS<VOI1
Where VCH is OC Pin Output “H” Voltage and V0I1 is overcurrent protection voltage
OC (pin 3) output H voltage (VCC-0.02V)  - overcurrent protection voltage (150mV)

Closed 2023-02-27.

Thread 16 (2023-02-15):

Test protection circuit in isolation

huffeec, 2023-02-15:
Use a spare board to populate only the Fs312F protection chip circuit to test on it's own.

huffeec, 2023-02-20:
I've soldered up a board with just components
U6 (The FS312F)
Q2 mosfets
C16 and R24

With a battery giving 3.76 V

U6 sees:
Vcc 3.75V
OD (p1) 2.9V
OC (p3) 3.75V
CS (p2) 1.2V

With a battery giving 2.9 V

U6 sees:
Vcc 2.9V
OD  2.5V
OC  2.9V
CS (p2) 1.2V

With a wire between q2 p3 and u6 p6
OD and OC give Vcc
and CS 0V

huffeec, 2023-02-27:
Using a bench supply to test U2:

P1 goes low at input below 2.9V
P3 goes low at input above 4.2V

So the chip is operating as expected.

q2 is showing input voltage across p1 and p3 regardless of the state of the U2 pins.

huffeec, 2023-02-27:
I'm confident U2 is behaving as expected and the problem is related to GND designations on the board.
I've reworked the circuits breaking the battery protection out into it's own sheet.
The switch has been removed from here to sit before the boost convertor.

Closed 2023-02-27.

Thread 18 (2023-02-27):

Zenner D8 and R28 in charging circuit

huffeec, 2023-02-27:
The Zenner in the charging circuit should prevent over voltage at Vcc.
[https://www.electronics-tutorials.ws/diode/diode_7.html](https://www.electronics-tutorials.ws/diode/diode_7.html)
Investigate what are appropriate values for R28 in this application

amcewen, 2025-01-03:
I'm assuming this is for the `v2.0` prototype?  We don't seem to have an `R28`  or a zener diode any more :grin:

Closed 2025-01-03.

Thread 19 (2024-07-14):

Upgrade to an ESP32

amcewen, 2024-07-14:
The ESP8266 is starting to lag too far behind the WLED capabilities.  Although we've still got lots in stock, maybe we can leave them for the Ackers Bell or Mersey Dot?

Anyway, we should move to one of the cheap ESP32 modules, and switch to the "mini" version to make the board smaller.

amcewen, 2024-07-14:
I'd been assuming we'd go with an ESP32-C3 **but** thinking about the new Bluetooth Auracast tech (the broadcast audio option), having a module that supports *that* would open up some interesting possibilities with the sound-reactive versions.

The Auracast stuff needs Bluetooth 5.2 or higher, which means we should go with the ESP32-C6-MINI-1-N4 over the C3

amcewen, 2024-11-06:
Tested the latest WLED on a C3 dev board, hooked up with a I2S microphone (an INMP441 on a breakout board this time) as [detailed in the audio-reactive guide on the WLED wiki](https://kno.wled.ge/advanced/audio-reactive/) and it seems perfectly responsive with ~150 LEDs.

So, given [support for the C6 will be some time away](https://github.com/Aircoookie/WLED/issues/3078) (and we might be able to upgrade the Bluetooth stack to support auracast on older boards, maybe?) we're going with a C3-MINI for this rework.

huffeec, 2024-11-06:
Looking at the schematic for the C3 there are less GPIOs than we need

Of the [15 available](https://www.espressif.com/sites/default/files/documentation/esp32-c3-mini-1_datasheet_en.pdf)

- 2 (IO18/19) are D+/-
- 2 rx/dx
- 3 IO2/08/09 are strapping pins for boot mode

Section 4.1 Chip Boot Mode Control says that "GPIO2 actually does not determine SPI Boot and Joint Download Boot mode, but it is recommended to pull this pin up due to glitches"

IO8 (d/c SPI Download High)

IO9 needs to be accessible (High SPI Low Download)

Leaving 8 accessible pins, the current design uses:

- 4 for level shifted data channels
- 2 for leds
- 2 pads for optional external crystal
- 1 for reset button
- -1 remaining

To provide I2S we need 3-4 pins available

We could use the two crystal pins but are still 3 pins short that we need to find from somewhere. Either from strapping pins (It seem odd to me that these are never available, or using less leds/data channels)

IO0 and IO1 are currently exposed as pads in case an external crystal is needed

huffeec, 2024-11-06:
[This page from Espressif](https://docs.espressif.com/projects/esptool/en/latest/esp32c3/advanced-topics/boot-mode-selection.html) seems to suggest that 08 needs to be pulled high in hardware which matches the [C3 mini data sheet example circuit - section 9
](https://www.espressif.com/sites/default/files/documentation/esp32-c3-mini-1_datasheet_en.pdf)

The page linked [refers to a dev kit schematic](https://dl.espressif.com/dl/schematics/esp32_devkitc_v4-sch-20180607a.pdf) that doesn't appear to have an IO8

huffeec, 2024-11-06:
For reference and to aid my memory, the [C3 mini dev kit schematic](https://dl.espressif.com/dl/schematics/SCH_ESP32-C3-DEVKITM-1_V1_20200915A.pdf) has 08 pulled high but not 02. Although the schematic is dated 2021 and the datasheet was updated in 2024 (V1.7) to change the boot pin requirements in 2024 so I suspect both are required

huffeec, 2024-11-06:
Tasks remaining
- [ ] Update references in schematic
- [ ] Reduce edge cut to width of <48mm in pcb
- [ ] Check for smaller footprint components eg L2/passives
- [ ] Add second unpopulated usb socket
- [ ] Retrace tracks
- [ ] Update silkscreen
- [ ] run DRC
- [ ] run DRC
- [ ] run DRC

amcewen, 2025-01-03:
The ESP32C3 on the prototypes seems to be working well, so closing this off

Closed 2025-01-03.

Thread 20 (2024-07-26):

Rework design for integrated charger/5V boost chip

amcewen, 2024-07-26:
TI have [a nice integrated battery charging and 5V boost chip](https://www.ti.com/lit/ds/symlink/bq25895m.pdf) that could replace both the charger and the 5V boost circuit.

Nice things about it are:
* 3.1A current from the 5V boost circuit, which would let us run more lights from it (currently it's ~1.5A IIRC, though that might include a bit of headroom so we're not running it at max output all the time)
* Fewer chips needed, so might be smaller
* Ability to charge at higher currents depending on USB charger attached

It'd be useful to compare the costs - I think it'll be more expensive than the current option, but it'd be useful to know roughly how much (so what's the total BoM cost for this circuit over the existing charger and 5V boost, inc. inductors, etc.); and maybe do a bit of a search through LCSC to see if there are any alternative all-in-one options.  Presumably it's a fairly popular circuit, given how many USB power banks there are.

huffeec, 2024-07-29:
Very ball park numbers gives a ~+$0.24 difference with this chip over the current setup.
I've not managed to find anything equivalent on LCSC. (finding anything on LCSC is a challenge though so I'll have another quick look at some point)

Old
Battery management – CN3791 $0.5
        + Power mosfet C308748 $0.25
Battery protection – FS312F-G $0.12 (discontinued at LCSC)
	+ Mosfets FS8205 $0.18 (discontinued at LCSC)
Boost converter – FP6276B $0.34
	+ inductor – C27442 $0.16

Total - **$1.55**

New
BQ25895M **$1.79**

amcewen, 2024-07-29:
Dismantling one of the Pimoroni battery packs, they've got a protection PCB internally, so dropping the battery protection should be okay.

There's a 2.2uH inductor on the sample circuit for the new chip, but that shouldn't make a massive difference - there seem to be some on LCSC that are super cheap ($0.03!) and even if I'm missing some of the more important criteria (was just a quick search for shielded ones, at 2.2uH with a 3.5A+ current rating) they'll likely not be massively more expensive.

Might be worth a quick scan of Kicad to see if that throws up any alternative options; maybe Tindie too?  But if we don't find anything cheaper I think a move to the BQ is worth doing.

huffeec, 2024-10-16:
[d6158d3](https://github.com/mcqn/my-bikes-got-led/commit/d6158d3ef8e8aa7f31227338dbe93214acebe4ec) has a rework that includes the battery management from #25

Sanity checking before layout needed:

* Is the switch circuit ok? It takes the JSM2302 Mosfet from the earlier versions, but without the battery protection chip. - Batt denotes all battery management side grounding, Gnd everything on the other side of the switch.
* Do we need the external 32.68KHz crystal for the c6 mini? The [datasheet for the module](https://www.espressif.com/sites/default/files/documentation/esp32-c6-mini-1_mini-1u_datasheet_en.pdf) pg32 and the schematic for the [dev kit ](https://docs.espressif.com/projects/esp-dev-kits/en/latest/_static/esp32-c6-devkitm-1/schematics/esp32-c6-devkitm-1-schematics.pdf)have it. I can't find much of a discussion about it though.

amcewen, 2024-10-16:
The [C6 datasheet](https://www.espressif.com/sites/default/files/documentation/esp32-c6_datasheet_en.pdf) lists that it includes a 40MHz crystal oscillator.  It also talks about the 32KHz crystal and points to [the Reset and Clock chapter in the ESP32-C6 Technical Reference Manual](https://www.espressif.com/sites/default/files/documentation/esp32-c6_technical_reference_manual_en.pdf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) (TBF the datasheet seems to be almost a 50-odd page index for the technical reference manual :rofl:)

Section 8.2.4.2 seems the most relevant:

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

Reading through that, it seems that the external 34KHz crystal is optional, because it's possible to use the internal 32KHz RC oscillator instead.  Presumably it's available to allow a more precise source rather than an RC circuit.  I'm thinking we skip it, but maybe include a couple of test points near the pins so we could tack one in (on the prototype at least?) if we have any problems

amcewen, 2024-10-16:
The switch circuit looks okay to me.  The battery packs we use have a protection circuit built-in, so I think it's correct to omit that from this version of the board.

huffeec, 2024-10-21:
[945ffdf](https://github.com/mcqn/my-bikes-got-led/commit/945ffdfe1df8e9bcc706f4c1dc4ae111a14a96aa) check in new design with charger/5V boost

amcewen, 2024-10-22:
Some review notes.

Charger circuit looks good.

Probably not a showstopper but do we still need two polyfuses?  I'm thinking it might be better to just have one between the boost 5V output and everything else - so it'd protect the 3V3 regulator (and so ESP), neopixels, plus any shorting of the breakout pins.

We've got a chunky trace for the 5V until it gets to `F2` and then the route from there to the LED connectors - `J2` and `J3` is a thin trace.  Maybe if we route all of the `5V` through `F1` and lose `F2`, then we could shift the `5V`/`GND`/`3V3` breakout pins nearer to the connector side, and route the `LED_Data` and `LED_Clk` lines on the back copper to the left of the breakouts rather than the right?  Then there'd be room for a fat `5V` trace on the back copper from the breakout to `J3`?

Haven't reviewed the ESP32-C6 circuit yet, but have covered everything else.

huffeec, 2024-10-22:
I have removed F2, DRC still passes.

On My Baby's the Enable pin is pulled high, the switch pulls reset and IO4 low

On the C6 there is no reset pin, the switch pulls enable low, via RC.
Boot mode is selected via gpio 08/09
In the [default circuit (page 32)](https://www.espressif.com/sites/default/files/documentation/esp32-c6-mini-1_mini-1u_datasheet_en.pdf) 08 is pulled high 09 is pulled up by internal resistor or pulled low via a jumper.

Table 3.3.2 Chip Boot Mode Control of the datasheet linked above shows this gives default SPI boot mode or Download boot if the jumper is connected.

Are we ok with this default behaviour or do we need to tie a gpio pin to the switch for the mod?

amcewen, 2024-10-22:
How would a non-techie user clear all their info from the board, if they sold/gave it to someone else?  How would anyone wipe the WiFi details if it was set to create an access point but you'd forgotten the password for it?

I don't mean for that to sound confrontational, I'm just laying out the reasons - I think they're the key ones - that I added the factory reset feature originally.  If there are other ways that we can achieve them then we might not need it any more.

Otherwise, if we'd need to do a bit of experimenting because there's now an RC circuit in the mix on the Enable pin, could we add a test point on that pin to let us breadboard the extra parts we'd need for a factory reset on the next rev?

huffeec, 2024-10-22:
Agreed, I guess I am asking two different questions at once.

Do we need to be able to toggle between SPI/Download boot mode? If so do we need a solderable jumper or pin headers?

How to implement the factory reset behaviour on this rev. My Baby's pulls reset high when the switch is pressed (Enable always on) C6 uses the switch to pull Enable low. Is a change of state enough on the factory reset GPIO?
For this rev is it enough to have a gpio connected to the switch via a breakable jumper and a test point on Enable? ie no additional RC for the GPIO?

amcewen, 2024-10-22:
Good point about boot mode.  If there's room for some sort of pin access for bootmode I think that'd be useful - with MiaB we've seen that sometimes the program-over-USB doesn't work properly and putting it into boot mode explicitly gets it out of that state.

And on the factory reset side, I don't think it matters which way the GPIO is pulled (though we'd need to update the usermod in WLED if it changes), but the board needs to still boot up if the switch is held closed rather than stay in reset.  I can't quite work out what the circuit would look like without breadboarding it to double-check, so I think a test  point on Enable would let us mod one of the prototype PCBs to work that out.  I'm not sure connecting the GPIO with a breakable jumper would be enough - feels like we might need to re-jig and/or add to the caps and resistor around there - so we can test with one of the broken-out-for-general-use GPIOs (and then pick a not-broken-out one for the proper implementation).

I guess if we're (potentially) desoldering one (or more) of `C12`, `C13` or `R11` for testing that, maybe soldering an extra wire to one of them would be as easy as a test point?  It'll only be on one board after all.  Feels like I'm talking myself out of any changes to this rev, and maybe it's just a new issue to address once we've got the hardware? :grinning:

huffeec, 2024-10-22:
If it helps make this decision. I've uploaded the files to JLC with a gpio connected to the switch and some test points in that region for hacking if needed. Just to gauge costs if nothing else...

For five boards delivered...... $150   Includes $25 setup fee, $50 loading fee $10/ea components.

I may have misremembered but it feels like they are getting less competitive...

It's left in the basket to think about

I've also learned that LCSC stock is not equal to JLC stock anymore.
So this has a [Molex](https://www.lcsc.com/product-detail/USB-Connectors_MOLEX-1054500101_C134092.html) USB connector instead of the [Amphenol](https://www.lcsc.com/product-detail/USB-Connectors_Amphenol-ICC-12401610E4-2A_C5119948.html)

amcewen, 2025-10-05:
We've got a two-pin header for `boot` mode; and have been happy with the design so far (plus WLED has an option for resetting the WiFi settings with the default switch GPIO, so I don't think we need our factory reset usermod any more).

Closed 2025-10-05.

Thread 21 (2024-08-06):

Pin access for redesign

huffeec, 2024-08-06:
With the new components #20 we will be able to slightly reduce the footprint of the board. With that in mind do we still want to expose all the pins of the esp32, provide a subset, or none at all?

The ESP32-C6-MINI-1-N4 #19 has USB serial, can we lose the UART header?

amcewen, 2024-08-07:
I think having a few pins available for other things is useful, but it doesn't need to be the full set.  Enough for a button (in WLED, so in addition to the usual bootstrapping ones), and an ADC and I2S pins to allow either option for the sound-reactive options (if the ADC can use one of the I2S pins that'd be fine, as you won't want both options at the same time)

The USB is an interesting question.  I'd not spotted it has that.  The tricky part, I think, is that the battery charger chip also wants the USB D+/D- pins.  I think that's to allow faster charging options, which would (probably) trump easier flashing?  Most of the time you could flash new versions over WiFi.

huffeec, 2024-08-07:
The DSEL pin can be used to switch use of D+/- pins as described [here](https://e2e.ti.com/support/power-management-group/power-management/f/power-management-forum/1020519/bq25895m-reference-circuit-for).

[reference circuit](https://www.ti.com/lit/ug/sluuba2b/sluuba2b.pdf )

But, this might be overcomplicating and not something we need to worry about?

amcewen, 2024-08-08:
Using the DSEL pin is tempting.  Looking at the circuit it'd be two extra components: a 2-channel switch and a pull-up resistor?

The TI switch is only available from Farnell with a 40-week lead time, but maybe [this NXP chip](https://uk.farnell.com/nxp/nx3dv42gu-115/analogue-switch-2-ch-dpdt-xqfn/dp/2749612RL) would be a suitable option?  That'd add ~43p to the BoM cost, which doesn't sound terrible for keeping USB support on the ESP32.

huffeec, 2024-08-08:
There isn't anything specific in the [c6 mini datasheet ](https://www.espressif.com/sites/default/files/documentation/esp32-c6-mini-1_mini-1u_datasheet_en.pdf)
but the [c6 series datasheet](https://www.espressif.com/sites/default/files/documentation/esp32-c6_datasheet_en.pdf) does show it's supports USB 2 but not 3

"USB 2.0 full speed compliant, capable of up to 12 Mbit/s transfer speed (Note that this controller does
not support the faster 480 Mbit/s high-speed transfer mode)"  4.2.1.6

huffeec, 2024-08-08:
The [NXP NX3DV42GU-115](https://www.lcsc.com/product-detail/Analog-Switches-Multiplexers_NXP-Semicon-NX3DV42GU-115_C2652483.html) is available at LCSC in single units ($0.82ea).

amcewen, 2024-08-08:
Sounds like USB multiplexing is a go :grinning:

huffeec, 2024-10-18:
This has moved on because of #25 (Using the IP5310 instead)

The current design has d+/- direct to the ESP as the battery management isn't using them.

Additional inputs available

- GPIO 18 and 19 are available through the spare channels of the level shifter
- 9 pin header
-- GPIO 02 is available as ADC input
-- 8, 9, 22, 23 also available as spare GPIO inputs
-- GPIO 06/07 available as SDA SCL
-- Remaining pins are 3v3 and GND
- RX, TX, GND and 5V (solder jumper) on a 6 pin header
- 2 x 3V3, 5V, GND
- Batt +/- as 2 pin head
- 5V, Data. GND 3pin header

5V, Data and GND test points
Test points on reverse for GPIO0/1 (External crystal)

There is also a test point on the battery management for the KEY pin in case we need that. And 3 unpopulated resistors VSET, RSET, VTHS. I don't think we'll need access to any other pins but there is space on the board if we do want to add extra test points for access

huffeec, 2024-10-21:
Closed with [945ffdf](https://github.com/mcqn/my-bikes-got-led/commit/945ffdfe1df8e9bcc706f4c1dc4ae111a14a96aa)

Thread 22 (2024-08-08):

Can we terminate the QON pin on the BQ25895M battery management IC

huffeec, 2024-08-08:
Issue to record discussion about what we want to do with the QON switch,

From the datasheet

"8.2.10 BATET (Q4) Control
8.2.10.1 BATFET Disable Mode (Shipping Mode)
To extend battery life and minimize power when system is powered off during system idle, shipping, or storage,
the device can turn off BATFET so that the system voltage is zero to minimize the battery leakage current. When
the host set BATFET_DIS bit, the charger can turn off BATFET immediately or delay by tSM_DLY as configurated
by BATFET_DLY bit.

8.2.10.2 BATFET Enable (Exit Shipping Mode)
When the BATFET is disabled (in shipping mode) and indicated by setting BATFET_DIS, one of the following
events can enable BATFET to restore system power:
1. Plug in adapter
2. Clear BATFET_DIS bit
3. Set REG_RST bit to reset all registers including BATFET_DIS bit to default (0)
4. A logic high to low transition on QON pin with tSHIPMODE deglitch time to enable BATFET to exit shipping
mode

8.2.10.3 BATFET Full System Reset
The BATFET functions as a load switch between battery and system when input source is not plugged-in. By
changing the state of BATFET from off to on, system connects to SYS can be effectively have a power-on-reset.
The QON pin supports push-button interface to reset system power without host by change the state of BATFET.
When the QON pin is driven to logic low for tQON_RST while input source is not plugged in and BATFET is
enabled (BATFET_DIS=0), the BATFET is turned off for tBATFET_RST and then it is re-enabled to reset system
power. This function can be disabled by setting BATFET_RST_EN bit to 0."

huffeec, 2024-10-18:
Fixed by #25

Closed 2024-10-18.

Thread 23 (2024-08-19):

J2/3 offer the extra channels on the level shifter, should the be breakable or soldered to connect

huffeec, 2024-08-19:

huffeec, 2024-10-18:
Have stuck with solder pads for this rev

Closed 2024-10-18.

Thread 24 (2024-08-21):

Boosted output is not available if USB input is connected (Battery charging)

huffeec, 2024-08-21:
The PMID pin of the BQ25895M chip provides the boosted output providing the OTG pin is high and Vbus is disconnected.

So with an input at the usb port the device will provide power management to use this input and/or the battery to give the system voltage.
However it can only provide the boosted output when the battery isn't charging (USB input removed) [8.2.5](https://www.ti.com/lit/ds/symlink/bq25895m.pdf)

This means we can operate lights only if a battery is connected but not a usb source eg power bank.

Can we live with this or do we need to find a different solution?

.

amcewen, 2024-08-21:
If there's power on Vbus then we could route that to the lights, no?  That'll be more efficient than dropping it to battery voltage and then boosting it back up anyway.  That's what the last design did, with an extra mosfet to switch the boost output off when there was external power.  So we might need to replicate that, but it also sounds a bit like the internal `RBFET` might perform that role?

huffeec, 2024-10-18:
Fixed by #25

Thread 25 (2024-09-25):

Alternatives to BQ25895M

huffeec, 2024-09-25:
Alternatives to the TI battery management chips, there are many options that would reduce the BOM costs. It's not obvious to me what the right choice is. Here are a couple to start.

[BQ25895M](https://www.lcsc.com/product-detail/Battery-Management_Texas-Instruments-BQ25895MRTWR_C485917.html)
[Boost output up to 3.1A @5V](https://www.lcsc.com/datasheet/lcsc_datasheet_2001181534_Texas-Instruments-BQ25895MRTWR_C485917.pdf)
LCSC costs
1+ $1.8218
10+ $1.6962

[INJOINIC IP5310](https://www.lcsc.com/product-detail/PMIC-Battery-Management_INJOINIC-IP5310_C191176.html/)
[Boost output up to 3.1A @ 5V](http://www.injoinic.com/wwwroot/uploads/files/20200221/a7a6128e03ee193cf35e48b28e3df9df.pdf)
LCSC costs
1+ 	$0.5921
10+  $0.4979

[ETA9740](https://www.lcsc.com/product-detail/Battery-Management-ICs_etasolution-ETA9740E8A_C7465512.html)
[Boost output up to 2.4A @5V](https://www.lcsc.com/datasheet/lcsc_datasheet_2307171444_etasolution-ETA9740E8A_C7465512.pdf)
5+ 	$0.2242
50+ $0.1782

amcewen, 2024-09-25:
From a sweep of my almost-lost-tabs...

[INJOINIC IP5322](https://www.lcsc.com/product-detail/Battery-Management_INJOINIC-IP5322_C188807.html)
[Boost output up to 3.1A @ 5V](http://www.injoinic.com/wwwroot/uploads/files/20200221/277b7d7f99700b3307be2cda1ca7000f.pdf)  Not quite sure why I'd saved that, though can (it seems) output 9V or 12V too
LCSC costs
1+ $0.8814
10+ $0.8629

[ETA9741](https://www.lcsc.com/product-detail/Battery-Management_etasolution-ETA9741E8A_C7465513.html)
[Boost output up to 2.4A @5V](https://www.lcsc.com/datasheet/lcsc_datasheet_2307171444_etasolution-ETA9741E8A_C7465513.pdf)
LCSC costs
1+ $0.2077
50+ $0.165

amcewen, 2024-09-25:
The key features we'd like (though the USB access to the ESP32 isn't a dealbreaker) are:

### USB access to both the charging chip (to negotiate higher currents) and the ESP32
That'd be nice, but 99% of the time the board will be on a bike and not plugged into a computer; and once WLED is on it then it'll be upgradeable over WiFi.

* The TI chip has support for multiplexing the USB lines so we can do USB to both the charger and to the ESP32.
* The IP5310 wouldn't support this
* The ETA chips might support this, depending on whether we needed to add resistors for higher current charging; as that might interfere with the ESP32

### USB-C access to support negotiation of higher current (we think/presume)
* The TI chip offers this
* The IP5310 offers this (and can negotiate output power at higher voltages too?)

### Direct USB 5V to output 5V alongside charging
So we can run the system while plugged into a power bank for extra running time.

* We *think* the TI chip can charge and run power to the output straight from the charging 5V simultaneously.
* It looks like the IP5310 would maybe run power straight from the charging 5V to the output 5V - depends if the mosfet control would switch off in those cases.  If it doesn't, we can use the resistor "trick" for USB2 to negotiate ~2A charging (which would mean that we **don't** actually need USB-C support) and the MOSFET and diode bypass
* For the ETA chips, we'd need to ~~add the bypass 5V with a MOSFET and diode, as we did in the second-version design~~ see if it can cope with a drain on the supply at the same time as it's charging

### Other notes
* The IP5322 doesn't seem to offer anything better than the IP5310 and is more expensive.
* The TI is more expensive and needs a multiplexer chip, so that seems to have itself out of the market
* The ETA chips are cheapest, ~~would need a MOSFET, diode and resistor to provide the "direct 5V" option~~ and use the same pin for 5V in and out, so maybe has some switching internally to decide whether or not to run the boost circuit?
* The IP5310 would need two MOSFETs, a transistor and a zener diode; and is ~$0.30 more than the ETA.  So with the added components that'd be another £2 or so on the RRP.
* There seem to be some boards on Seeed/Aliexpress using the ETA9740, but I couldn't find anything using the ETA9741

amcewen, 2024-09-25:
I've ordered [one of these boards](https://www.aliexpress.com/item/1005007291941402.html) so we can try out the ETA9740

huffeec, 2024-09-25:
As far as I can tell [this](https://docs.rs-online.com/5199/A700000011325029.pdf) is the data sheet for that board

amcewen, 2024-09-25:
And I've ordered [an IP5310 breakout too](https://www.aliexpress.com/item/1005007457766086.html)

amcewen, 2024-10-07:
It's using an IP5328 but here's a talk about someone building a circuit using it to build a crazy power bank: https://berlin-ak.ftp.media.ccc.de/events/mrmcd/mrmcd24/h264-hd/mrmcd24-330-eng-Designing_a_power_bank_inside_a_can_of_Volt_Cola_hd.mp4

huffeec, 2024-10-11:
Just as a reference [Carl Bugeja](https://youtube.com/carlbugeja)'s project [Coin cell](https://microbots.io/products/codecell) uses the [BQ24232](https://www.ti.com/product/BQ24232) I'm not sure how useful it is for us (Max output current 1.7A)

huffeec, 2024-10-11:
Initial tests of the ETA on the Seeed board

It can charge and provide output at the same time, but.

Disconnecting the usb input causes a brief output interruption ~1 second
Connecting power input while an output load is present prevents charging. So the load needs to be turned off if an input is applied

The IP5328 appears to offer what we need.

It allows input and output simultaneously and there is no interruption if the input is removed.

Running a test to make sure it detects when a battery is fully charged.

amcewen, 2024-10-11:
FYI this is the [datasheet for the usual batteries we'd pair with it](https://cdn.shopify.com/s/files/1/0174/1800/files/PKcell_ICR18650_6600mAh_Final.pdf?11497089046215477949)

huffeec, 2024-10-11:
Charging light still flashing after several hours. Will test again next week.

Battery voltage has reached 4.14V

amcewen, 2024-10-14:
Stuck it on charge again this afternoon and checked in on it about an hour, hour-and-a-half later and the lights were all lit and had stopped flashing.  Battery voltage was at 4.138V on my multimeter at that point, so presumably it was pretty close last time.

amcewen, 2025-01-03:
The prototypes with the IP5310 have been working well (although we probably want to add a power LED or similar to stop it auto-powering off, but that's covered in #31)

Closed 2025-01-03.

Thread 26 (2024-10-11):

IP5310 battery spec pin settings

huffeec, 2024-10-11:
This IC has a series of battery related pins, it appears that they're not critical to this application but for some it will be useful to have pads for 0 resistors to give us the option to experiment if we need to.

**These should be removed before a production run.**

RSET - Battery impedance value set with a resistor to gnd. Unpopulated/floating sets impedance to
22.5mOhm

VSET - Sets battery maximum, floating = 4.2V pulled to gnd 4.35V set to Batt 4.4V
I have included a non populated 0 Ohm resistor giving us options for 4.2 or 4.35V

VTHS - Voltage thresholds for charging lights Non populated with option to pull to Batt (pg 17 of datasheet)

NTC is battery temperature monitor. This is set fixed with a 51K resistor to GND to not use. Not changeable but included in the issue for reference/ in case we decide to add it.

LIGHT Optional flashlight pin not used tied to ground.

KEY Push button one press on / two press off. Does not function if Vin connected so not used in this design (Floating)

[English language datasheet](http://www.injoinic.com/wwwroot/uploads/files/20200221/a7a6128e03ee193cf35e48b28e3df9df.pdf)

Closed 2025-01-10.

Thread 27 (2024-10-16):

SN74AHCT125 level shifter out of stock at LCSC

huffeec, 2024-10-16:
The current TI level shifter chip isn't in stock at LCSC for prototypes. There is an equivalent in TSSOP package
[SN74AHCT125](https://www.lcsc.com/product-detail/Buffers-Drivers-Receivers-Transceivers_Texas-Instruments-SN74AHCT125PWR_C36365.html)

huffeec, 2025-01-10:
This chip works as expected on the first V2 boards.

Closed 2025-01-10.

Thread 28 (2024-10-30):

My bollards got LED extension

huffeec, 2024-10-30:
From our visit to mini roads a suggested game was light up wands that kids visit in order. This lead to a discussion about if the My Bike's board would be suitable for powering lights and using the ESP C3 as the communication to the microbits. They could communicate with the Microbits over Bluetooth (as opposed to 'Radio')

It would be possible to reduce the width of the new revision to <50mm so that it would fit inside Pex tubing.

For this we would need:

A second USB footprint (Unpopulated) 90deg around the board for use in the bollards to recharge the battery.

Move/remove the slot to accommodate the optional usb socket placement. Possibly by also moving the mounting holes.

Of course this may be madness but the issue is open to record it just in case..

amcewen, 2025-01-03:
We should get some prototypes with the USB in the "wand orientation" populated for the next run, partly to confirm this approach works (given the "normal orientation" with unpopulated footprints has worked fine on the prototypes), and partly because we need to make some wands :grinning:

amcewen, 2025-01-31:
We got some prototypes made in the "wand orientation" and they work nicely!

huffeec, 2025-01-31:
Needed to complete prototype bollard
Hardware
- [ ] Buy plumbers and caps 2x per bollard
- [ ] Source pipe
- [ ] 3d print (?) hook to hold the end of a single strip of neopixel
- [ ] 3d printed insert to mount board and battery

Software IDF
- [ ] Complete basic comms between My Bikes boards and Microbits. Initial tests with IDF  and Zephyr respectively has worked. @huffeec  to tidy and create folder in this repo
- [ ] Establish a measure of RSSI as a proxy for proximity
- [ ] Implement LED driving
- [ ] Receive and respond to Set/Reset/Check game events.
- [ ] Create a mesh network of bollards **?
** Test range of comms without a network first

Software Zephyr (In [https://github.com/mcqn/bike-head](https://github.com/mcqn/bike-head) )

- [ ] BLE advertising for proximity testsing
- [ ] Set/Reset/check modes for game  A, B A+B button events

amcewen, 2025-02-05:
The end-caps look decent.  The key dimensions from them are: OD 55.6mm, ID 50mm (although the aperture for the cap end has an ID of 45.6mm).  The coupler has an OD of 61.5mm.

So we need to find some PEX or similarly translucent pipe for the rest of it.

huffeec, 2025-02-07:
From the site visit this morning. It looks like the perimeter path will be too larger for the range of the bollards, but the two tarmac areas either side of the school are available to us.

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

huffeec, 2025-02-07:
This [Bluetooth developer study guide](https://www.bluetooth.com/bluetooth-resources/bluetooth-le-developer-starter-kit/) has a worked example of Microbit proximity service advertising. Although building for the current version fails with Kconfig errors.

For the MBiGL side the [ESP idf proximity sensor](https://github.com/espressif/esp-idf/tree/master/examples/bluetooth/nimble/ble_proximity_sensor/proximity_sensor_cent) listens for the same support for the Link Loss service (0x1803) as primary service UUID

This builds and runs on our hardware, but currently fails because the service I've set up (a  basic [beacon](https://github.com/zephyrproject-rtos/zephyr/tree/main/samples/bluetooth/beacon) in Zephyr is advertising the correct service but not providing the required response.

amcewen, 2025-02-10:
Looking at options for a light-diffusing tube...
* [Clear PVC, OD= 50mm av.bore =42.6mm](https://www.plasticpipeshop.co.uk/50mm-Clear-PVC-Pipe-25m-Length_p_1623.html)
* [Clear PVC, OD= 63mm av.bore =57mm](https://www.plasticpipeshop.co.uk/63mm-Clear-PVC-Pipe-25m-Length_p_1626.html) (so this should fit over the end-cap, rather than into it)
* [Clear acrylic, available in 50mm or 60mm OD, with 2, 3,4 or 5mm wall thickness](https://www.simplyplastics.com/catalog/acrylic-tube/clear-extruded-acrylic-tube/c-24/c-81/p-216).  So the 60mm with 2mm wall would fit over the end-cap; the 50mm inside it.
* [Frosted acrylic, available in 50mm with 3mm wall thickness](https://www.simplyplastics.com/catalog/acrylic-tube/frosted-extruded-acrylic-tube/c-24/c-81/p-302) (available in 60mm too, but the ID would be too small to fit over the end-cap)
* [Clear polycarbonate tube](https://www.theplasticshop.co.uk/polycarbonate-tube.html) available in 50mm or 60mm OD with a variety of wall thicknesses.
* [100% recycled clear acrylic tube](https://www.plastock.co.uk/products/eco-acrylic-cast-clear-tube?variant=42888277786848), available in 50mm OD (the minimum wall thickness is 3mm, so the 60mm OD would have too narrow an ID)
* [Opal frosted polycarb tube](https://www.plastock.co.uk/products/polycarbonate-frosted-opal-tube?variant=43481549340896), 50mm OD with a 2mm wall (they seem out of stock of their 60mm OD with 2mm wall)

I think the frosted ones would be the best option for diffusion, and polycarb is going to be more resilient than acrylic

amcewen, 2025-02-10:
I've ordered 4m of the frosted polycarb.

huffeec, 2025-02-12:
Battling with the [Proximity sensor](https://github.com/espressif/esp-idf/blob/master/examples/bluetooth/nimble/ble_proximity_sensor/proximity_sensor_prph/README.md) requires an active Link loss service broadcasting. The example in the tutorial above won't compile with newer Zephyr and was proving tricky.

@amcewen has successfully installed [ble_adv_scan_combined](https://github.com/espressif/esp-idf/tree/master/examples/bluetooth/hci/ble_adv_scan_combined ) on our boards and detected a Microbit running [Peripheral](https://github.com/zephyrproject-rtos/zephyr/tree/main/samples/bluetooth/peripheral)

I'll add copies of these two samples to the repo as a starting point for implementing .

### Microbit

#### Controller x1

Manages the game running with button presses

- A `Set `the game: Broadcast to all bollards to enter waiting mode
- B `Check`: Broadcast to all the bollards to check status and display correct/incorrect indicator
- A+B `Reset `Broadcast to all the Parcels to generate a random destination number 1-4 and broadcast to bollards to enter waiting mode

#### Parcel x6
Broadcast destination number to bollards
Listen for reset command from Controller

### MBiGL (ESP32)

#### Bollard x4

Have a fixed bollard number 1-4

Separate tasks to manage Bluetooth comms and display

**Bluetooth**
Maintain list of Parcel devices within given range (RSSI) over the last five seconds and if they are at the correct bollard or not

Listen for Set/Check/Reset broadcasts from controller. Use a hop counter when rebroadcasting this signal to other bollards to extend the range

On `Set `call display to enter waiting mode
On `Check` call correct/incorrect display based on state of Parcel devices seen list
On `Reset` enter waiting mode

**Display**
Receive calls to set lights based on game state. Ideally animated sequences

huffeec, 2025-02-14:
[f405a26](https://github.com/mcqn/my-bikes-got-led/commit/f405a26a3102af75f5cde4f48f63300b642a1339)
 ·has a working BLE service advert with a 'data' payload which can be set to the game states check/set/rest. Will probably also need to be an additional state for 'in play'

Basic microbit button code is working, but my initial attempt at polling an A+B press isn't

huffeec, 2025-02-17:
ESP example code separates the name (0x09) and the date (0x24) in the large array that is produced by a scan event,

In the short term we can just scan on 0x24 and record the data and mac address to determine controller and parcel devices and their state.

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

amcewen, 2025-02-19:
I've added a new task for the LED display, which runs a rainbow strobe at present.  Also added `main/app_led.h` which has the API that the rest of the game should use.  Right now it just prints out to the log that it was called, and returns an `-ENOTSUP` error code.

I don't think the calling code (in this case) will care about any return codes from it, but it was more for futurproofing.  The calls are:
* `LEDs_Start()` - this starts the task and sets up the Arduino subsystem.  It should be called somewhere near the start of `app_main` (before it gets into a loop at least)
* `LEDs_Success()` - displays a rainbow to show the success condition
* `LEDs_Failure()` - displays a red, slow flash(?) to show a failure condition
* `LEDs_Waiting()` - displays a yellow "game in progress" condition.  Maybe a larson scanner, maybe just fading up and down in brightness?
* `LEDs_Progress(uint8_t aPercentDone)` - for debugging more so than the game itself, fills the strip with colour to the given percentage.

amcewen, 2025-02-19:
I've added a basic implementation of the display now.  All of the API functions listed above work, and the strip animates for each state.  It starts up with the display off.

* Failure has the whole strip fade up and down in brightness of all-red
* Success is the FastLED cylon rainbow
* Waiting is a yellow Larson scanner
* Progress lights the given percentage of LEDs (and fades out higher ones if the level drops, rather than going straight to off; seems a bit smoother in operation)

I've got a bit of simple code that sets it to failure if the signal strength is too low; then progress above that; and success if it gets strong enough.  However, that's in `app_bt.c` and I couldn't remember if you still had changes in that to commit @huffeec, so I've left that not-commited for now.  It's pretty trivial:
```
if (rssi[i] < -90)
{
    LEDs_Failure();
}
else if (rssi[i] < -50)
{
    LEDs_Progress(100+rssi[i]);
}
else
{
    LEDs_Success();
}
```

I've also added a call to `LEDs_Waiting();` after the call to `LEDs_Start();` to (a) test that state, and (b) show something at startup for now.

huffeec, 2025-02-21:
Current state of parcel and controller boards.

Parcel: On start/reset the board picks and broadcasts an 0x24 response message with 'BOL' and a random number between 0-3
The Micro:bit reset button acts as the game reset for this parcel and selects a new BOL num.

Controller:  On start the boards broadcasts an 0x24 response message with  'Check' as the data payload.
The Micro:bit buttons toggle the state of the game between 'Set' (A) or 'Check' (B) by changing the response message payload to 'Set'/'Check'

Both boards will need laser cut shapes to hold them and the battery. The controller will need the functions of the buttons etched onto it. The parcel board just needs to hold the battery and board. A hole to give access to the reset button is needed.

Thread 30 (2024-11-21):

Problems programming r20241810 board over USB

amcewen, 2024-11-21:
We've had five of the `r20241810` boards fabbed.  ~~This issue is for notes and anything that needs addressing before the next production batch:~~ (minor points covered in #29; other bigger things spun out as their own issues; this one edited as it's become the "get USB working" issue)

amcewen, 2024-11-21:
* We haven't got the USB working yet, so need to program the board via the "FTDI" serial header.
* The LED data line is on `GPIO 5` so needs to be configured in WLED to bring the lights to life

amcewen, 2024-12-19:
Got the scope set up to monitor `D+` and `D-`.

This is a Museum in a Box board as a reference:

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

The straight-from-production My Bike's Got LED board seems to have half the amplitude that we'd want on the `D+` line:

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

And it seems not very square!

Tapping into the USB (rather than ESP32-C3) side of the resistors with some wires to a USB-C breakout board gives a much squarer trace with the right sort of amplitude on both `D+` and `D-`:

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

However, it fails in seemingly the same manner on the Linux side.

We tried programming the ESP (over serial) with the CodeCell getting started example, just to ensure nothing was using the USB or other important pins, but that made no difference (beyond us spotting issue #31)

We set the trigger on the scope to catch when the USB protocol activity starts (when `D+` went high for the 2nd or 3rd time, depending on the exact trigger level for it) and then hand-decoded the USB traffic, referring to [this USB explainer for voltage levels and bits](https://www.engineersgarage.com/signal-and-encoding-of-usb-system-part-5-6/) and [this one for how those bits map into USB packets](https://beyondlogic.org/usbnutshell/usb3.shtml)

There seem to be a bunch of `ping` packets, to different addresses, but after an initial intact packet we then saw one with the last bit of the `PID` flipped (and so invalid) followed by one that looks like a retransmission with an intact `PID`.  The invalid-then-intact pairings were each for different addresses, and all were at 1ms intervals (as we'd expect to stop the device going into suspend).  We didn't capture enough data in the scope memory to get beyond the pings (we saw about 8 of those IIRC)

Would be good to repeat the exercise monitoring a Museum in a Box board to see what the successful bring up of USB looks like.

amcewen, 2024-12-19:
I was thinking some more overnight about how the "invalid ping" packets were always wrong by the last bit and how it seemed strange for it to be so regular.

I think our decoding was off by 1-bit.  If what we thought was the last bit of the sync byte was actually the first bit of the PID then we'd have PIDs that were always 10100101.  So they're all NAKs rather than pings.

huffeec, 2024-12-20:
Equally  out by two would give a consistent 1101 which has the correct form for the SOF token packet.

amcewen, 2024-12-24:
Had a look at the Museum in a Box USB traffic today.

Got lots of SOF packets at the start, at 1ms intervals.
* `00000001 10100101 01110011 01111110`
* `00000001 10100101 11110011 01100000`
* `00000001 10100101 00001011 01110111`

First capture wasn't getting anything beyond those.  I think that's because it's still only ~8ms after insertion of the cable, so maybe the ESP32 is still starting up.

The traces on from the Museum in a Box board look like this, as another reference.

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

Switching to triggering on a *falling* `D+` (well, the one that's high before the packet starts) and then the Nth edge seems roughly to be the Nth packet.  I think the rest of the traffic is too quick for the triggering to catch properly (or at least I can't work out the right parameters to catch it) on the rising edge.

Skipping 25 on the falling edge seems to catch something interesting:

* some 1ms interval SOF packets...
* `00000001 10100101 00001110 00100001` another SOF packet
* 1ms delay then at -5.6us - `00000001 10110100 00000000 00001000` - Setup token, I think?  Address 0, endpoint 0
* at -2.32us - `00000001 11000011 00000001 01100000 00000000 10000000 00000000 00000000 00000010 00000000 10111011 00101001` - a DATA0 packet, 8 bytes(?)
* at 6.32uS - `00000001 01001011` - an ACK
* at 8.84us - `00000001 10010110 00000000 00001000` - an IN token (host wants to read from the device).  Address 0, endpoint 0
* at 12.16us - `00000001 11010010 01001000 10000000 00000000 01000000 11110111 01000000 10000000 00000010 01011100 00001100 10000000 00001000 10000000 10000000 10000000 01000000 11000000 10000000 00000010 01101010` - a DATA1 packet, 18 bytes(?)
* at 27.46us - `00000001 01001011` - an ACK
* at 29.39us - `00000001 10000111 00000000 00001000` - an OUT token (host wants to send to the device).  Address 0, endpoint 0
* at 32.66us - `00000001 11010010 00000000 00000000` - a DATA1 packet, 0 bytes I think.
* at 35.97us - `00000001 01001011` - an ACK
* at 257.3us goes into SE0 (both D+ and D- low) until at least 21.41mS - capture ended then.

Trying the modded MBiGL board, capturing after 12 edges, otherwise it seemed to just get the SE0 trace for all of it (if I tried any higher)

It was actually plugged into the onboard USB-C socket though!  The probes were onto the wires plugged into the breadboard with the USB-C breakout; and the battery was charging (just the final LED flashing IIRC), in case that affects things?

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

* Some 1ms interval SOF packets...
* at 50ms - `00000001 10100101 10101110 10010011` - an SOF packet
* at 50.66ms - `00000001 10110100 00000000 00001000` - Setup token?  Address 0, endpoint 0
* at 50.67ms - `00000001 11000011 00000001 01100000 00000000 10000000 00000000 0000...00010 00000000 10111011 00101001` - a DATA0 packet (the `...` were some more 0s that I didn't work though decoding the exact count)
* at 50.68ms - `00000001 10110100 00000000 00010000` - another Setup token??  That's address 0, endpoint 1 - but that might be a mis-decoding?
* at 50.69ms - `00000001 11000011 00000001 01100000 00000000 10000000 00000000 00000000 00000010 00000000 10111011 00101001` - a DATA0 packet, 8 bytes.  Identical to the last DATA0 packet, and to the one from the Museum in a Box capture
* at 50.698ms (a noticeable gap compared to the gap between packets so far, or during all of the Museum in a Box capture) - `00000001 10110100 00000000 00001000` - another Setup token?  Address 0, endpoint 0
* at 50.701ms - `00000001 11000011 00000001 01100000 00000000 10000000 00000000 00000000 00000010 00000000 10111011 00101001` - another identical DATA0 packet
* at 50.99ms - `00000001 10100101 01101110 10010001` - back to SOF

There's then another burst of traffic at 51.01ms - I need to pick up decoding again there.  The capture is saved on the scope as `mbgl0.bin`

However, from a skim over it, there are two or three more bursts of traffic and then it drops to SE0 state.

From some further, higher-level decoding, it seems that a "Setup stage" is a Setup packet followed by a DATA0 packet, both sent by the host, and then an ACK (if it was received okay) from the device.

In the Museum in a Box example, that ACK comes through, so things move onto a "Data stage": that's an IN packet from the host to ask for some data, a data packet from the device, and then an ACK from the host; followed by the "Status stage", where an OUT packet is sent from the host followed by a zero-length data packet from the host, then an ACK from the device.

The My Bike's Got LED trace seems to show no response from the ESP32, and the host retrying the "Setup stage" a few times.

[https://www.beyondlogic.org/usbnutshell/usb6.shtml] details the format of the setup packet, which is 8 bytes long.  Decoding it:
* `00000001` - request type: device to host; standard; recipient is device
* `01100000` - request: "get descriptor"
* `00000000 10000000` - a `wValue` of 256, which defines the descriptor type desired
* `00000000 00000000` - index or offset of 0
* `00000010 00000000` - if there's a data phase, 64 bytes should be transferred

amcewen, 2024-12-27:
* tried the board I've been using to see what that's like.  The scope traces look similar: pretty square with a bit of ringing after each transition.  Didn't decode in detail, but could see a similar shorter packet followed by a long, presumably`DATA0`, packet and then a pause before it tries again.  With the pause being the gap where the ESP32 should provide the `ACK`.
* Tried the probes on the ESP32C3 side of the resistors and that looked *very* wrong:
  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
  Both `D+` and `D-` looked similar, although on this capture there's only `D+` as I'd removed the probe on `D-` in case it made any difference
* Checked the resistors `R15` and `R16` in the Kicad files.  They're specced as 22 ohm 0402.  The Farnell part numbers assigned to them are the right value but the wrong size.  More importantly for these test boards, the LCSC part number is the correct size, but 2.2k ohm.  That might be the problem :zany_face:
* Moved the tacked-on wires on the main test board to the ESP32C3 side of those resistors, and the board enumerated on USB first time when I plugged it into my laptop and showed up as `/dev/ttyACM0`.

amcewen, 2024-12-30:
I've ordered some of [these 22R 0402 resistors from Farnell](https://uk.farnell.com/neohm-te-connectivity/crg0402j22r/res-22r-5-0-063w-0402-thick-film/dp/1174143) so we can swap some out and confirm that the resistors are the problem.

amcewen, 2024-12-31:
The resistors arrived today; I replaced the ones on the prototype board I've been testing, and it shows up as `/dev/ttyACM0`, I've seen serial output from it, and I can reprogram it over USB! :tada:

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

huffeec, 2025-01-08:
Replicated this on another board

Closed 2025-01-08.

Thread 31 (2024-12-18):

ESP32-C3 on its own doesn't draw enough power to keep the charger chip on

amcewen, 2024-12-18:
The `r20241810` boards auto power off after ~30 seconds when running on battery if they're just running basic code on the ESP32-C3.

From the datasheet for the charging chip, that's because it's drawing less than 45mA and that triggers an auto shutoff feature.

Maybe we should add a "Power" LED to bump up the minimum current draw sufficiently to keep it running?

huffeec, 2025-01-10:
After struggling to source an led capable of handling this current D25 has been removed. R27 set as R120

There is a [register setting](https://github.com/Andyzug/PiBat_IP5310/blob/main/IP5310%20REG%20V1.2.zh-CN.en.pdf) that extends the 'boost low current shutdown time' but the maximum is 63mins.

SYS_CTL2 0X0E 2:0

amcewen, 2025-07-18:
Checked it again with the latest production boards and it seems to continue running well.

Closed 2025-07-18.

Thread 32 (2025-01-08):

Ensure headers are on the same 0.1" grid

huffeec, 2025-01-08:
Testing the I2S capabilities with a PCM1808 it's become apparent that 5v and 3v are needed to drive the ADC.
On the V2 board these are on different headers. So it would be useful if they aligned to the same grid

huffeec, 2025-01-10:
All headers aligned to the same 0.1" grid to allow for a shield

J5/6 (3v/5v/gnd)
J10 (GPIO)
J11 (Boot)
J31 (Serial)
J40 (LightData/5v/Gnd)
J41 (level shifted IO 3/4)
J50 (Battery)

Added in https://github.com/mcqn/my-bikes-got-led/commit/48e101aa2594887cc6f01d369a36b21093264ba0

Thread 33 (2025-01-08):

Web USB flashing of WLED

huffeec, 2025-01-08:
Initial testing of [https://install.wled.me/](https://install.wled.me/) only worked if the board was put into boot mode.

There were other problems flashing the boards by other methods so this may not be necessary usually. Just making a note that the ESP32C3 can be flashed this way.

There is also an unoffical version to try.
[https://wled-install.github.io/](https://wled-install.github.io/)

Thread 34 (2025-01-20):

Apply for OSHW certification

huffeec, 2025-01-20:
Following the process from [My Baby's got LED](https://github.com/mcqn/my-babys-got-led) applying at [https://application.oshwa.org/apply](https://application.oshwa.org/apply)
We will also need photographs of the new boards

- [x] @huffeec Draft
- [ ] @amcewen updated/approved
- [ ] @huffeec Applied

**BASIC INFORMATION
SECTION 1 OF 4**
This part of the form asks for basic information about the responsible party for the project to be certified, such as the name of the individual, company, or organization certifying the project and contact information for any future correspondence from OSHWA regarding your certification.

This certification is on behalf of a: Company
Name of Individual, Company, or Organization Responsible for the Certified Item: MCQN Ltd
If not an Individual, name of Individual with Authority to Bind the Company or Organization: Adrian McEwen

**Contact Information**
Country: United Kingdom
Street Address Line 1: DoES Liverpool, The Tapestry
Street Address Line 2: 68-76 Kempston Street
City/town/village: Liverpool
State/Province/Region: Merseyside
Zip code/postal code: L3 8HL
OSHWA Contact Email Address: redacted
Public contact email address: [info@mcqn.com](mailto:info@mcqn.com)

**PROJECT INFORMATION
SECTION 2 OF 4**
This part of the form asks for information about the project you wish to certify. Information submitted here will appear on your project’s profile listing.

Project name: My Bike's Got LED
Project version: r20250110
Have you previously registered a version(s) of your project with OSHWA? No
Project description: My Bike's Got LED is a portable LED driver board using WLED to drive individually addressable LEDs at 5V from LIPO batteries. It incorporates a battery charging circuit over USB which also provides an input for a secondary battery. It uses an ESP32 C3 mini chip and can be controlled using its own WiFi network or by connecting to an existing network. The development and documentation for the board is available on github, and the board is manufactured by mcqn and sold on Tindie.
Project website: mcqn.com/ibal234
Primary Project Type: IOT
Additional Project Types: Arts, Electronics, Home Connection
Project Keywords: WLED, MQTT

Where can the documentation be found for your project?: https://github.com/mcqn/my-bikes-got-led

- [ ] All project documentation and design files are available in the preferred format for making changes.

Does your project incorporate or build upon other open projects that are not currently certified by OSHWA? If so, use this space to cite those projects

|Citation Title | Citation URL|
|-- | --|
|WLED | https://github.com/Aircoookie/WLED|

**LICENSING INFORMATION
SECTION 3 OF 4**

This part of the form asks for information about your project’s
licensing. In order to qualify for OSHWA certification, you must have
chosen an open source license for your hardware, your software (if any),
 and your documentation. Your licenses for each of these elements will
appear on your project’s profile listing.
What license is your project's hardware licensed under? CERN
What license is your project's software licensed under? MIT
What license is your project's documentation licensed under? CC BY-SA

|Statement | Response | Explanation|
-- | -- | --
|The project is licensed in a way to allow for modifications and derivative works without commercial restriction. | Yes |  
|There is no restriction within my control to selling or giving away the project documentation. | Yes |  
|Where possible, I have chosen to use components in my hardware that are openly licensed. | Yes |  
|I understand and comply with the "Creator Contribution requirement," explained in the Requirements for Certification. | Yes |  
|There is no restriction on the use by persons or groups, or by the field of endeavor. | Yes |  
|The rights granted by any license on the project applies to all whom the work is redistributed to. | Yes |  
|The rights granted under any license on the project do not depend on the licensed work being part of a specific product. | Yes |  
|The rights granted under any license on the project do not restrict  other hardware or software, for example by requiring that all other  hardware or software sold with the item be open source. | No | The WLED software uses a MIT licence and can be used in other  non-open projects, but the hardware is restricted under the CERN Open  Hardware Licence Version 2 - Strongly Reciprocal.|
|The rights granted under any license on the project are technology neutral. | Yes |  

**CERTIFICATION
SECTION 4 OF 4**
This part of the form asks you to certify that you agree to specific terms of the [OSHWA Certification Mark License Agreement](https://certification.oshwa.org/license-agreement).

You agree to the following terms:

I have provided OSHWA with accurate contact information, recognize that all official communications from OSHWA will be directed to that contact information, and will update that contact information as necessary.
I will only use the certification mark in compliance with official certification guidelines.
I acknowledge that all right, title, and interest in the certification mark remains with OSHWA.
I acknowledge that OSHWA has the right to enforce violations of the use of the mark. This enforcement may involve financial penalties for misuse in bad faith.
I have the ability to bind those responsible for the certified item to this agreement.

If you do not agree with any of the above terms, please explain.
Provide a brief explanation (500 characters)
Relationship to certified item: I am the primary developer of the certified item, as well as a manufacturer and retailer of the item as a commercial product.

I agree to the terms of the OSHWA Open Source Hardware Certification Mark License Agreement, including the Requirements for Certification and Usage Guidelines incorporated by reference and including license terms that are not present in or conflict with this web form. I acknowledge that by agreeing to the terms of the OSHWA Open Source Hardware Certification Mark License Agreement that I am binding the entity listed to the License Agreement. I recognize that I will receive my unique identification number that allows me to promote my project as OSHWA Open Source Hardware Certified in compliance with the user guidelines via the email provided to OSHWA after submitting this form.

If you are the parent or legal guardian entering into this agreement on behalf of an individual under the age of 18, please provide your name to certify that you also agree to be bound by this agreement.: Not applicable.

amcewen, 2025-02-16:
Looks good.  I've submitted it, given I was already looking through it.  As above, though I added "Wearables" and "IOT" to the "Additional Project Types" section.

huffeec, 2025-04-07:
Certified as UK000073
https://certification.oshwa.org/uk000073.html

Closed 2025-04-07.

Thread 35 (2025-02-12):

My bollards got led - 3d printing

huffeec, 2025-02-12:
Breaking out from #28 for the mechanicals

Pipe and connectors have been bought, to complete the build we will need:

- [ ] 50mm opaque pipe to make a sleeve at the bottom of the bollard to contain the electricals.
- [ ] Plug piece to fit into the base and hold the bollard. This piece needs to allow access to the bottom connect so that it can be unscrewed for the power switch and charging.
- [ ] Holder for battery and board to fit within the tube. Needs to have access to the usb port for charging and accommodation for a toggle switch
- [ ] Hook for top of tube to hold lights in place.

amcewen, 2025-02-15:
Made a first pass at the plug piece.  It's on the printer at the moment, and will be done in about 9 hours.

amcewen, 2025-02-17:
Screwfix won't sell the 50mm pipe from the Islington branch, but when discussing it we decided actually just to print all of that section.

Also made an assortment of tweaks to the sizes after testing the first print:
* made the "finger gap" round the cap wider for better access
* slimmed down the outer diameter slightly, as it wouldn't quite fit into the base
* narrowed the inner hole so the pipe shouldn't wobble when fitted

It's on the printer now, going to be a 21 hour print in total!

amcewen, 2025-02-19:
The new plug/sleeve works really nicely.  The second print failed as it ran out of filament (turns out the 32m of filament it needed is more than "a lot" when you're looking at what's left on the spool.  There are two new prints running with fresh 1kg spools on the DoES Liverpool Ultimakers at the moment.

I've cut the pipe for the first bollard - 66cm long, and the two LED strips to go inside - each has 30 LEDs (so is 50cm long); the LED strips are wired into the `data` and `clk` pins on the My Bike's Got LED board.

With the LED strips removed from the waterproofing sleeve, they short if they're placed back-to-back and it's tricky to pull them taught inside the pipe.  I've cut a strip of polyprop (checked in as `light-backing.svg`) to act as a backing; I think they'll stick pretty well to that with double-sided tape (only tried a couple of short sections to tack it in place initially).  For future builds we should get the adhesive-backed LED strips to begin with 😁

The polyprop has a small hole in each end, which I think will make it easier to fasten in place.  It seems to work okay with the hook 3D print and a Post Office elastic band, although that's a little long.

Still needed for the first prototype:
* [ ] Soldering switch to the My Bike's Got LED board
* [ ] Sticking the LED strips to the carrier polyprop
* [ ] Soldering LED strips to the My Bike's Got LED board
* [ ] Working out how to secure the bottom end of the LED strip/carrier
* [ ] Glue the pipe parts together (I got a tub of ABS solvent weld from Screwfix, feels like the first thing to try?)
* [ ] Flashing code to it

huffeec, 2025-02-21:
From the first test outside today it's become clear we need the light strips attached to the side of the tubes. They don't give off enough light to be clearly visible if it is defused.

For this both [lastmile_boardHolder.FCStd](https://github.com/mcqn/my-bikes-got-led/blob/main/my-bollards-got-led/physical/lastmile_boardHolder.FCStd) and [lastmile_tophook.FCStd](https://github.com/mcqn/my-bikes-got-led/blob/main/my-bollards-got-led/physical/lastmile_tophook.FCStd) need reworking. The polyprop strips will still need to be under some tension to keep the strips against the tube walls all the way down.

amcewen, 2025-02-25:
I've extended the pegs on the LED tensioner disc (went as high as 5mm but that stuck out too much to go into the tube) to 4mm, and flared the extrude by 10&deg; which means (at 5mm extrude at least) that the LED backing strips stay on them once attached.  And added the notch for the lower version to fit into the spacer piece.

I also trimmed the board-to-battery disc by 1mm, as that was too much of an interference fit with the tube.

amcewen, 2025-02-25:
Did some trial fitting, and it's coming together nicely.  A few tweaks:
* The overall length is a bit long, if we can lose 9-10mm from the battery "compartment" that would help
* We should shorten the LED backing too
* Some holes in the piece between the battery and the PCB would be useful, to allow wires to pass through

The battery test ran on the rainbow pattern (with three strips) for 9h30m before I turned it off.

huffeec, 2025-02-26:
Remaining printing

- [ ] [lastmile_boardBrace.FCStd](https://github.com/mcqn/my-bikes-got-led/blob/main/my-bollards-got-led/physical/lastmile_boardBrace.FCStd) x2
- [ ] [lastmile_boardBottomPlug.FCStd](https://github.com/mcqn/my-bikes-got-led/blob/main/my-bollards-got-led/physical/lastmile_boardBottomPlug.FCStd) x3
- [ ] [LED-tensioner-top.FCStd](https://github.com/mcqn/my-bikes-got-led/blob/main/my-bollards-got-led/physical/LED-tensioner-top.FCStd) x2

amcewen, 2025-03-12:
The LED tensioner disc has a tendency to skew when it's fed into the tube, and the bottom one is totally inaccessible to try to straighten out.

I think if we made it thicker it would then seat properly in the tube and not have any room to twist.

amcewen, 2025-03-13:
I made some notes on how to assemble things in a `README.md` in the folder with the 3D design files.  Needs the names updating, and links adding, to the various 3D files (and tweaking if we find more things to note when assembling the remaining 3 bollards)

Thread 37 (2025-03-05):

Make container for sound reactive components of My Bike's got LED

huffeec, 2025-03-05:
Container to include

- My bikes got led board
- PCM1808 ADC [breakout](https://www.aliexpress.com/item/1005005819147396.html)
- Panel mount 3.5mm jack socket
- On/off switch
- Battery
- Nice to have > input jack for handlebar mounted switch to cycle

Box needs to be robust and weather resistant.

Possible to remove battery with a bracket underneath the main case suitable for a four cell pack. It should be easy to remove the battery without pulling on the wires. This may require MBiGL boards with the vertical mount JST's

I've got in touch with Peloton to arrange having a look at the current setup.

amcewen, 2025-03-05:
I've ordered another of the PCM1808 breakouts, and some more panel-mount jack sockets so we can make up a second container.

The weather-resistant side of things *could* be it getting put into a saddle-bag again (doesn't have to be, just noting it as still an option)

huffeec, 2025-09-26:
The pink box is in for repair.

The wires to the switch had become detached and removed copper traces near sw3 & q1. This also removed p1 of q1. I have replaced q1 and resoldered the switch wires.

It is possible to connect to wled on the DoES network. The sound reactive option was unticked so I can't see which order the audio pins need connecting in. Will check with the white box before I reconnect the new ADC.

Closed 2025-04-07.

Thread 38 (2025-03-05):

Shuffle pins for the I2S input to match footprint for INMP441 microphone?

amcewen, 2025-03-05:
It would be nice if there was an even simpler way to add an I2S mic, and given the popularity of the 2 rows of 3 pin 0.1" headers on the small circular INMP441 microphone, it'd be nice if the relevant pins on the MBiGL PCB were lined up so you could solder in two rows of headers and the the microphone would just plug in.

huffeec, 2025-03-25:
https://github.com/mcqn/my-bikes-got-led/commit/d60d5c8d278dbaae7465e52ee73bb3c98afd6561 has this arrangement for the header. Needs a more intuitive silkscreen and sense check the pins used for the microphone and remote button.

huffeec, 2025-05-02:
Silk screen tidied and pins added to [readme](https://github.com/mcqn/my-bikes-got-led/tree/main/electronics)

amcewen, 2025-10-05:
Ordered a batch of boards with this on, so assuming it works, we'll then be able to close this.

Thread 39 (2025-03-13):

Update the GettingStarted document for the new board version

amcewen, 2025-03-13:
Things I expect we'll need to update (I've not checked what the old one says):
* That it's an ESP32C3 now (so name which version of the default WLED release builds to use?)
* Which pins to configure for the LEDs
* The extra level-shift pins for expansion
* New higher current limit - something along the lines of "about 2.5A.  The chip can provide 3.1A but some needs to be reserved for the processor"
* Extra section pointing to the audio-reactive instructions, and suggesting pins to use.  If nothing else, it would give us somewhere to note which pins we use for the INMP441 and the PCM1808
* Anything about the charging?  Maybe just mentioning that there's one on-board and explaining the LEDs?

Closed 2025-04-07.

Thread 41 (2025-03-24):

Add My Bike's got LED project to Hackaday

huffeec, 2025-03-24:
Does MCQN already have an account?

huffeec, 2025-03-25:
I wondered about sending the link to the OSHWA video, that mentions both the bike board and the bollards

huffeec, 2025-04-30:
I've drafted an email to hackaday to send when the changes to catalogue pages 234 and 251 are live.

For 234 I've copied the format from 223 (My Baby's..) as yet there are none of the bike photographs from the postcards. This might be worth adding down the line? I've used a product image as the main image and uploaded this to Tindie and  somewhere safe

huffeec, 2025-05-02:
Email sent to tips@hackaday.com

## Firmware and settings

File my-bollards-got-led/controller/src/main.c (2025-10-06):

/* main.c - Application main entry point */

/*
 * Copyright (c) 2015-2016 Intel Corporation
 *
 * SPDX-License-Identifier: Apache-2.0
 */

#include <zephyr/types.h>
#include <stddef.h>
#include <string.h>
#include <errno.h>
#include <zephyr/sys/printk.h>
#include <zephyr/sys/byteorder.h>
#include <zephyr/kernel.h>
#include <zephyr/logging/log.h>

#include <zephyr/settings/settings.h>

#include <zephyr/bluetooth/bluetooth.h>
#include <zephyr/bluetooth/gap.h>


//See : https://github.com/fduignan/zephyr_bbc_microbit_v2/tree/main
#include "matrix.h"
#include "buttons.h"


/*

Manages the game running with button presses

    A Set the game: Broadcast to all bollards to enter waiting mode
    B Check: Broadcast to all the bollards to check status and display correct/incorrect indicator
    A+B Reset Broadcast to all the Parcels to generate a random destination number 1-4 and broadcast to bollards to enter waiting mode


*/


LOG_MODULE_REGISTER(Last_Mile_Controller, LOG_LEVEL_INF);


volatile bool last_button = true;

#define DEVICE_NAME CONFIG_BT_DEVICE_NAME
#define DEVICE_NAME_LEN (sizeof(DEVICE_NAME) - 1)


/*  Declare the advertising packet */
static const struct bt_data ad[] = {
	/*  Set the advertising flags */
	BT_DATA_BYTES(BT_DATA_FLAGS, BT_LE_AD_NO_BREDR),
	/*  Set the advertising packet data  */
	BT_DATA(BT_DATA_NAME_COMPLETE, DEVICE_NAME, DEVICE_NAME_LEN),

};

/* Declare the URL data to include in the scan response */
static unsigned char check_data[] = { 0x0C, 'C', 'H', 'E', 'C', 'K' };
static unsigned char set_data[] = { 0x0C, 'S', 'E', 'T' };




/* Declare the scan response packet */
struct bt_data sd[] = {
	/* Include the payload data in the scan response packet */
	BT_DATA(BT_DATA_URI, check_data, sizeof(check_data)),
};


void button_a_callback(void)
{


LOG_INF("button A\n");
last_button = false;

/*
	if(get_buttonB()){
		matrix_put_pattern(0x1f,0);
	} else {
		matrix_put_pattern(0,0);
	}
*/
}

void button_b_callback(void)
{
LOG_INF("button B\n");
last_button = true;

}


int main(void)
{

	int err;
	/* Enable the Bluetooth LE stack */
	err = bt_enable(NULL);
	if (err) {
		LOG_ERR("Bluetooth init failed (err %d)\n", err);
		return -1;
	}
        settings_subsys_init();
	if (IS_ENABLED(CONFIG_SETTINGS)) {
		settings_load();
	}

	LOG_INF("Bluetooth initialized\n");
	


	/*  Start advertising */
	err = bt_le_adv_start(BT_LE_ADV_CONN, ad, ARRAY_SIZE(ad), sd, ARRAY_SIZE(sd));
       if (err) {
		LOG_ERR("Advertising failed to start (err %d)\n", err);
		return -1;
	}

	// Initialise microbit io
	int ret;
  	ret = buttons_begin();
  	if (ret < 0)
  	{
		printk("Error initializing the buttons\n");
		return -1;
	}
	ret = matrix_begin();
	if (ret < 0)
  	{
		printk("Error initializing the matrix\n");
		return -2;
	}
	attach_callback_to_button_a(button_a_callback);
	attach_callback_to_button_b(button_b_callback);

	LOG_INF("Advertising successfully started\n");	
	bool current_button = last_button;
	while(1) {
		k_msleep(100);	
		if(current_button != last_button) {
		 	
			LOG_INF("Set data\n");
			if(last_button) {
				sd->data = check_data;
				sd->data_len = sizeof(check_data);
			} else {
				sd->data = set_data;
				sd->data_len = sizeof(set_data);			
			}
			current_button = last_button;

			LOG_INF("Update advertising\n");
			bt_le_adv_update_data(ad, ARRAY_SIZE(ad),
			      sd, ARRAY_SIZE(sd));
			LOG_INF("Return\n");
		}		
		
		
	}
	return 0;
}

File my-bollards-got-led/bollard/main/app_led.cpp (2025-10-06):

#include <freertos/FreeRTOS.h>
#include <freertos/queue.h>
#include "Arduino.h"
#include "FastLED.h"
#include "esp_log.h"
#include "app_led.h"

static const char* TAG = "LEDs";

const int kPinLEDSideA = 5;
const int kPinLEDSideB = 6;
const int kPinLEDSideC = 3;
// How many LEDs are on each side
const int kLEDCount = 30;

CRGB gLEDsA[kLEDCount];
CRGB gLEDsB[kLEDCount];
CRGB gLEDsC[kLEDCount];

QueueHandle_t gLEDsTaskInbox =NULL; // Queue for messages *to* the LEDs task
EventGroupHandle_t gLEDsTaskEventGroup =NULL; // Event Group for signalling responses *from* the LEDs task
// Events used for comms to the task
enum eLEDsEvent
{
    eLEDsEventSuccess = 0,
    eLEDsEventFailure,
    eLEDsEventWaiting,
    eLEDsEventProgress,
    eLEDsEventPattern
};
// Bits in the gLEDsTaskEventGroup
const EventBits_t kLEDsFlagSuccess    = 1 << 0;
const EventBits_t kLEDsFlagFailure    = 1 << 1;
const EventBits_t kLEDsFlagWaiting    = 1 << 2;
const EventBits_t kLEDsFlagProgress   = 1 << 3;
const EventBits_t kLEDsFlagPattern    = 1 << 4;
typedef struct t_LEDsEvent
{
    eLEDsEvent iEvent;
    int iError;
    void* iData;
} tLEDsEvent;
typedef struct t_LEDsPatternEvent
{
    uint8_t iRed;
    uint8_t iGreen;
    uint8_t iBlue;
    enum eLEDPattern iPattern;
} tLEDsPatternEvent;

// Internal states for the display
enum eDisplayState
{
    eDisplayOff,
    eDisplaySuccess,
    eDisplayFailure,
    eDisplayWaiting,
    eDisplayProgress,
    eDisplayPattern
};

void LEDsFadeAll()
{
    for (int i =0; i < kLEDCount; i++)
    {
        gLEDsA[i].nscale8(250);
        gLEDsB[i].nscale8(250);
        gLEDsC[i].nscale8(250);
    }
}


TaskHandle_t gLEDsTask =NULL;
static void led_task(void* aParam)
{
    // Get things ready for Arduino
    ESP_LOGW(TAG, "Let's Go!");
    initArduino();

    ESP_LOGW(TAG, "LED task is running");
    FastLED.addLeds<WS2812,kPinLEDSideA,GRB>(gLEDsA,kLEDCount);
    FastLED.addLeds<WS2812,kPinLEDSideB,GRB>(gLEDsB,kLEDCount);
    FastLED.addLeds<WS2812,kPinLEDSideC,GRB>(gLEDsC,kLEDCount);
    FastLED.setBrightness(84);

    uint8_t hue = 0;
    int idx = 0;
    bool direction = true;
    eDisplayState currentState = eDisplayOff;
    uint8_t progressLevel = 0;
    enum eLEDPattern currentPattern = ePatternNone;
    CRGB currentPatternColour;
    while (1)
    {
        // See if there are any messages for us
        tLEDsEvent ev;
        if (xQueueReceive(gLEDsTaskInbox, &ev, 10) == pdTRUE)
        {
            ESP_LOGI(TAG, "Received %d\n", ev.iEvent);
            switch (ev.iEvent)
            {
            case eLEDsEventSuccess:
            {
                currentState = eDisplaySuccess;
                // Confirm the message
                xEventGroupSetBits(gLEDsTaskEventGroup, kLEDsFlagSuccess);
            }
            break;
            case eLEDsEventFailure:
            {
                currentState = eDisplayFailure;
                // Confirm the message
                xEventGroupSetBits(gLEDsTaskEventGroup, kLEDsFlagFailure);
            }
            break;
            case eLEDsEventWaiting:
            {
                currentState = eDisplayWaiting;
                // Confirm the message
                xEventGroupSetBits(gLEDsTaskEventGroup, kLEDsFlagWaiting);
            }
            break;
            case eLEDsEventProgress:
            {
                currentState = eDisplayProgress;
                progressLevel = (uint32_t)(ev.iData) & 0xff;
                ESP_LOGW(TAG, "Progress level is %d%%", progressLevel);
                // Confirm the message
                xEventGroupSetBits(gLEDsTaskEventGroup, kLEDsFlagProgress);
            }
            break;
            case eLEDsEventPattern:
            {
                currentState = eDisplayPattern;
                tLEDsPatternEvent* pattern = (tLEDsPatternEvent*)ev.iData;
                currentPattern = pattern->iPattern;
                currentPatternColour = CRGB(pattern->iRed, pattern->iGreen, pattern->iBlue);
                // Confirm the message
                xEventGroupSetBits(gLEDsTaskEventGroup, kLEDsFlagPattern);
            }
            break;
            default:
                ESP_LOGI(TAG, "Unexpected event: %d", ev.iEvent);
                break;
            };
        }
        // Now animate the LEDs based on our state
        switch (currentState)
        {
        case eDisplayOff:
        {
            LEDsFadeAll();
            // Show the leds
            FastLED.show();
        }
        break;
        case eDisplaySuccess:
        {
            // Set the i'th led to red 
            gLEDsA[idx] = CHSV(hue++, 255, 255);
            gLEDsB[idx] = CHSV(hue++, 255, 255);
            gLEDsC[idx] = CHSV(hue++, 255, 255);
            // Move to the next LED based on our direction
            if (direction)
            {
                idx++;
                if (idx >= kLEDCount)
                {
                    idx = kLEDCount-1;
                    direction = false;
                }
            }
            else
            {
                idx--;
                if (idx < 0)
                {
                    idx = 0;
                    direction = true;
                }
            }

            // Show the leds
            FastLED.show();
            //ESP_LOGW(TAG, "hue: %d, idx: %d, direction: %s", hue, idx, (direction? "up" : "down"));

            LEDsFadeAll();
        }
        break;
        case eDisplayFailure:
        {
            // We're going to abuse "hue" as the brightness level
            for (int i =0; i < kLEDCount; i++)
            {
                gLEDsA[i] = CHSV(0, 255, hue);
                gLEDsB[i] = CHSV(0, 255, hue);
                gLEDsC[i] = CHSV(0, 255, hue);
            }
            // Move to the next brightness based on our direction
            if (direction)
            {
                hue++;
                if (hue == 255)
                {
                    direction = false;
                }
            }
            else
            {
                hue--;
                if (hue == 0)
                {
                    direction = true;
                }
            }
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

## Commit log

2021-10-10 Most of schematic done and first pass at a few chunks of the board layout. Part of #1
    [BaseESP8266.sch, MyBikesGotLED.kicad_pcb, MyBikesGotLED.sch]
2021-10-12 Changed switch, finished laying out PCB.
    [BaseESP8266.sch, MyBikesGotLED.kicad_pcb, MyBikesGotLED.sch]
2021-10-12 Change cap part number to one that's in stock.
    [MyBikesGotLED.sch]
2022-01-17 Design for first prototype of a handlebar-mounted button. Part of #7
    [HandlebarButtonMount.FCStd]
2022-06-01 Added gcode for charging circuit
    [test_CNC_circuit.kicad_pcb, test_CNC_circuit.kicad_sch]
2022-06-01 Gcode for charging circuit
    [test_CNC_circuit.kicad_pcb, test_CNC_circuit.kicad_sch]
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2022-10-07 Boost circuit testing files
    [boostcircuit_board.svg.kicad_pcb, boostcircuit_board.svg.kicad_sch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]
2022-10-14 New boost circuit added
    [MyBikesGotLED.kicad_pcb, MyBikesGotLED.kicad_sch]
2022-10-14 Reduced board size for v2
    [MyBikesGotLED.kicad_pcb]
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2022-10-19 Added stock list of components
    [MBiGL_Stock.ods]
2022-11-04 V2 Board needs: final traces, silkscreen and DRC
    [BaseESP8266.kicad_sch, MyBikesGotLED.kicad_pcb, MyBikesGotLED.kicad_sch]
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2022-12-07 DRC errors removed - Needs Silkscreen tidy
    [MyBikesGotLED.kicad_pcb]
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2023-01-16 Fixed batt mod jpr and added cu fills
    [MyBikesGotLED.kicad_pcb, battery.kicad_sch]
2023-01-18 Fixed U3 Cu and logos for silkscreen
    [MyBikesGotLED.kicad_pcb]
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2023-02-27 reworked battery management based on V2 tests
    [MyBikesGotLED.kicad_sch, battery.kicad_sch, battery_protection.kicad_sch]
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2024-08-08 Swapped ESP8266 for ESP32, added BQ25895M battery management, and NX3DV42GU switch for d+/-
    [BQ25895MRTWR.step, BaseESP8266.kicad_sch, MyBikesGotLED.kicad_pcb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]
2024-08-21 Connected esp pins, current battery protection using TI chip. check in before chip change
    [BaseESP32_C6.kicad_sch, MyBikesGotLED.kicad_pcb, MyBikesGotLED.kicad_sch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]
2024-09-27 check in with TI battery management chip before we replace with Injoinic or ETA chips
    [MyBikesGotLED.kicad_sch]
2024-10-11 Replaced batt management with IP5310, power switch still needed in schematic
    [BaseESP32_C6.kicad_sch, MyBikesGotLED.kicad_pcb, MyBikesGotLED.kicad_sch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]
2024-10-16 Schematic complete except final pinouts for ESP and checking of swtich circuit and external crystal for ESP
    [BaseESP32_C6.kicad_sch, MyBikesGotLED.kicad_sch, battery.kicad_sch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]
2024-10-17 Tracks placed, DRC passess excpept silkscreen. Needs BOM before fabrication
    [BaseESP32_C6.kicad_sch, MyBikesGotLED.kicad_pcb, MyBikesGotLED.kicad_sch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]
2024-10-18 Fixed ground planes, tidied silkscreen, added keepout zone for ESP
    [BaseESP32_C6.kicad_sch, MyBikesGotLED.kicad_pcb]
2024-10-18 Tidied tracks, added keepouts for ESP. Parts sourced except leds and small caps
    [BaseESP32_C6.kicad_sch, MyBikesGotLED.kicad_pcb, MyBikesGotLED.kicad_sch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]
2024-10-21 /production added with all LCSC stock in BOM
    [BaseESP32_C6.kicad_sch, MyBikesGotLED.kicad_pcb, MyBikesGotLED.kicad_sch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]
2024-10-22 Add boot pins, replace usb
    [BaseESP32_C6.kicad_sch, MyBikesGotLED.kicad_pcb, MyBikesGotLED.kicad_sch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]
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2024-11-06 Swapped C6 for C3, connected new gpios
    [BaseESP32_C3.kicad_sch, MyBikesGotLED.kicad_pcb, MyBikesGotLED.kicad_sch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]
2024-11-08 components placed and tracks routed, needs silkscreen, drc and checking
    [BaseESP32_C3.kicad_sch, MyBikesGotLED.kicad_pcb, MyBikesGotLED.kicad_sch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]
2024-11-11 Finished silkscreen, added new LSCS codes to reflect current JLC stock
    [BaseESP32_C3.kicad_sch, MyBikesGotLED.kicad_pcb, MyBikesGotLED.kicad_sch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]
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2024-11-13 Move R12 silkscreen; tidy keepout area copper near the C3. Part of #29
    [BaseESP32_C3.kicad_sch, MyBikesGotLED.kicad_pcb, battery.kicad_sch]
2025-01-06 v2.1 pcb tweaks from #29. Silkscreen, LED spec and the keep alive power led outstanding
    [BaseESP32_C3.kicad_sch, MyBikesGotLED.kicad_pcb, MyBikesGotLED.kicad_sch]
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2025-01-13 Fixed designators to match up same parts
    [BaseESP32_C3.kicad_sch, MyBikesGotLED.kicad_sch, battery.kicad_sch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]
2025-02-10 Update production with zip, bom and pos for sideways batt/usb
    [bom.csv, designators.csv, positions.csv]
2025-02-10 Swapped out of stock inductor to C280565
    [MyBikesGotLED.kicad_pcb, battery.kicad_sch, battery_protection.kicad_sch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]
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2025-02-15 First pass at the plug/sleeve to fit between the pipe and the base. Part of #35
    [base-sleeve.FCStd]
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2025-02-17 Second run with tighter tolerances and just using the off-the-shelf end-cap, rather than that plus coupler and pipe. Part of #35
    [base-sleeve.FCStd]
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2025-02-24 Add revised tensioner for triple-strip design. Part of #35
    [LED-tensioner-top.FCStd]
2025-02-24 Add red-light/green-light game; fine-tune proximity threshold; fix LED colour ordering. Part of #28
    [app_led.cpp]
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2025-02-25 Fine-tune diameter so it fits into the tube better. Part of #35
    [lastmile_boardToBattery.FCStd]
2025-02-25 Add slot for securing the lower mount; extend pegs slightly and flare them for better capturing of the LED backing. Part of #35
    [LED-tensioner-top.FCStd]
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2025-03-07 First pass at a container for board, 2x2 battery pack, chunky switch, 3.5mm jack and PCM1808
    [MBiGL_soundreactive.FCStd]
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2025-03-13 Make the LED tensioner 10mm thicker so it should be less likely to twist in the tube. Part of #35
    [LED-tensioner-top.FCStd, lastmile_boardBrace.FCStd]
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2025-03-21 Shorter LED backing strip for triple-strip design. Part of #35
2025-03-21 Make PCB slot 0.2mm wider and nudge mounting holes up 0.5mm for easier fitting to the PCB. Part of #35
    [lastmile_boardBottomPlug.FCStd]
2025-03-25 Changed gpio to create header for INMP441 microphone. Needs silkscreen tidy
    [MyBikesGotLED.kicad_pcb, battery.kicad_sch]
2025-04-03 Update to enclosed loop instead of hook to increase strength
    [lastmile_tophook.FCStd]
2025-05-02 Updated silkscreen and readme for microphone version of the board
    [BaseESP32_C3.kicad_sch, MyBikesGotLED.kicad_pcb]
2025-10-03 Improve (hopefully) grounding by adding more vias to ground and shortening some of the traces on the bottom.
    [MyBikesGotLED.kicad_pcb]
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2025-10-06 Updates to the base sleeve (splitting it in two I think, so it can be added to an assembled LightBeam). Part of #35
    [base-sleeve.FCStd]
2025-10-06 Updates to parcel and controller firmwares (I think the versions we used in the workshop). Part of #28
    [MyBikesGotLED.kicad_pcb, bom.csv, designators.csv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]
2025-10-15 Fix typo in readme for INMP441 pin description
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2025-10-27 Add OSHW certification to the silkscreen on the board #43 completed
    [MyBikesGotLED.kicad_pcb]
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2025-11-10 Tweaks to the make the handlebar button aperture larger and the diameter tuned for my gravel bike. Part of #7
    [HandlebarButtonMount.FCStd]
2025-11-10 Initial design of a laser-cut cardboard insert for the packaging of a kit. Part of #45
    [MBiGL-BoxInsert.FCStd, MyBikesGotLED-PCB.FCStd]
2025-11-10 Set correct thickness of carboard for insert; fine-tune tabs. Part of #45
    [MBiGL-BoxInsert.FCStd, MyBikesGotLED-PCB.FCStd]
2025-11-14 Box insert reworked to hook over the PCB panel to hold it down. Part of #45
    [MBiGL-BoxInsert.FCStd]
2025-12-05 Resize packaging insert for the alternate shipping boxes we've got. Part of #45
    [MBiGL-BoxInsert.FCStd]
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
